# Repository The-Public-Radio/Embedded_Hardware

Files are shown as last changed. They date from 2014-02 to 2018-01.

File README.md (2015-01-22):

# PR_Public_Radio
Created 2013.12.17
by Spencer Wright |
Updated by Spencer Wright 2015.01.21

## LICENSE
In the interest of collaboration and good will, the files herein are offered for public use. Just don't be a jerk about it, etc., and do let us know if we've screwed something really big up:).
The Public Radio is licensed under a Creative Commons Attribution 4.0 License. For more info, visit https://creativecommons.org/licenses/by/4.0/

## PROJECT DESCRIPTION
The Public Radio is a single channel, single speaker FM receiver. 
As a piece of hardware, it was intended to be as simple as possible. One midrange speaker mounted inside a simple enclosure, with a single switched knob which controls power and adjusts volume.

## SYNOPSIS
The Public Radio is a project which spans industrial design, embedded systems design, and firmware. The files located within this project comprise a subset of the data reqired to fully complete ThePublic Radio, though efforts are being made to completely describe the project from top to bottom.

## CREDITS
The work herein is primarily a collaboration between Spencer Wright (http://pencerw.com) and Zach Dunham (http://zachdunham.com) though much of it was adapted heavily from friendly sources. In particular, early versions of the firmware was adapted directly from Nathan Seidle et al (Sparkfun). Special thanks also goes to Todd Bailey (http://blog.narrat1ve.com/) and Andy Warner (https://github.com/andyw-lala?tab=activity)

## Board and Layout

PR90XX is a circular PCB with an OD of 70mm and a 23mm circular cutout at its center. The cutout is designed such that the radio's speaker drops partly through the PCB; its backside passes through the cutout. The antenna and trim pot are additionally mounted directly to the board and pass through the top of the lid. Two sets of two AA battery clips are mounted on the bottom side of the board to house the two AA batteries.

Early on in the project, we planned on building a custom aluminum enclosure, but decided to protoype using an off-the-shelf container - a Ball brand mason jar. The enclosure requires one custom manufactured part: a replacement lid, to which the speaker, potentiometer, and electronics mount.

## CONTAINED HEREIN
* Embedded systems design files: Namely .brd, .sch, possibly gerbers. These will remain up-to-date, so long as we can stay on our game:)
* Firmware: Arduino sketches, library files (header & source). 
* Miscellaneous tools: This currently comprises of just a shell script used to create CSVs from EAGLE exports, which generally suck. The script is okay, though.

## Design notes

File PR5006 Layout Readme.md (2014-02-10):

#PUBLIC RADIO PR5006 Layout, Circuit Topology  
This document by Zach Dunham, 2014.02.08
Additional input by Spencer Wright

———————

##Overview 

The Public Radio v1.3 contains a significant revision in its PCB, PR5006. PR5006 consists of a mechanically tuned, FM receiver with included amplifier, speaker, AA batteries, tuning trimpot, and volume/power pot. The radio is delivered pre-tuned to the listeners chosen FM station. The radio includes a class-D amplifier, small (roughly 1”) speaker and switched potentiometer for power and and volume control. The radio runs at 3V off of two AA batteries that are fixed to the bottom of the PCB. Reception is permitted through the use of either a telescoping antenna or a fixed, solid stainless steel rod. The assembly is housed in a mason jar and attached to a custom lid.  

##Board and Layout 

PR5006 is a circular PCB with an OD of 70mm and a 23mm circular cutout at its center. The cutout is designed such that the radio's speaker drops partly through the PCB; its backside passes through the cutout allowing the solder lugs to be soldered directly to the board. The antenna and trim pot are additionally mounted directly to the board and pass through the top of the lid. Two sets of two AA battery clips are mounted on the bottom side of the board to house the two AA batteries.  

##Si4831 FM Receiver 

PR5006 utilizes the Si4831 chip in a 24 pin, SSOP package. Si4831 is a mechanically tuned digital CMOS AM/FM receiver. PR5006 only utilizes the FM functionality of the radio. Connections are as follows:

* Pins 1 & 2 - indicate stereo signal and station reception, respectively. Pin 1 is left floating since we are only functioning in mono mode. Pin 2 is tied high via R4 to set the radio in “volume mode” as opposed to “bass/treble mode” and tied high through R5 in series with an LED to indicate reception.  
* Pins 2 & 3 - form the tuning circuit of the radio along with C1, C2, trimpot R10, R1 and R3. Varying the resistance between these to pins varies the center frequency in the FM range. The radio calls for 413K at 1% between the band select pin and pin 1 of the trim pot. To keep within this tolerance we broke the 413K resistor into two resistors at 412K and 1K values.  
* Pin 5 - is the band select. According to the data sheet, pin 5 wants to see 77K resistance to ground to set the band select at 87-108MHz
* Pin 6,7 - NC 
* Pin 8 - is the FMI pin which consists of an ESD protection diode and inductor L1 to ground inline with a capacitor, C3 to pin 8 forming a high pass filter. Additionally, because our design places the antenna roughly 30 mm from pin 8, and to limit noise on the FMI line, we’ve placed restricts on both the top and bottom layer ground planes around the antenna trace.  
* Pin 9, 10, 11, 12 - tied to ground. Pin 9 is the RFGND, Pins 10, 11, 12 are part of the AM circuit tied to ground. Note, our testing with showed no loss of FM reception tying the AM to ground or leaving it floating.  
* Pin 13, 14 - also ground pins 
* Pin 15 - is the reset pin, tied high through R6 inline with C4 to ground 
* Pin 16, 17 - volume or bass/treble control. By tying pin 2 high we’re utilizing volume mode, and by tying pins 16 & 17 to ground we’re setting the output to maximum volume.  
* Pin 18 & 19 - are pins for the external 32.768 KHz oscillator with necessary loading caps (C6 and C8) tied to ground. 
* Pins 20, 21, 22 - are the power and bypass pins. Pins 20 and 21 - VDD1 and VDD2 - are connected to VCC through C5, C7.  The other leg of C5 and C7 are connected to pin 22 which is the IC’s internal bypass pin. Additionally, to mitigate noise C5 and C7 are inline with a ferrite bead connected to VCC.  
* Pins 23 and 24 - left out and right out signal to the audio amplifier

##TPA2005d1 1.4 W Mono Audio Amp
PR5006 uses this class-d audio amp to power its 1” full range driver.  

* Pin 1 - shutdown pin which is tied high through R8 inline with C10 to ground for a roughly 1/4 second delayed power up.
* Pin 2 - NC 
* Pin 3 - positive differential input from the output of the radio connected via coupling capacitor C9 and gain setting resistor R7, for a gain of roughly 6.  
* Pin 4 - negative differential input, same values as pin 3
* Pin 5 - positive output, connected to the speaker 
* Pin 6 - VDD connected to VCC through decoupling capacitors C12 and C13 along with a ferrite bead, L2
* Pin 7 - GND
* Pin 8 - negative output, connected to the speaker 

Notes!  
PR5006 has no reverse polarity protection.  The bottom solder mask design aims to provide the correct battery orientation. The following version will most likely incorporate a synchronous rectifier.

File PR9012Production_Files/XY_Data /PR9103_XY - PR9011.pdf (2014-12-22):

ITEM | PR9011 X/Y | NOTES | Do not place listed as yellow
DATE | 12.15.2014
PREPARED BY | Zach Dunham
NOTES | Development Board
CONTACT | info@thepublicrad.io
RefID | Description | Package | XPos mm | YPos mm | Orientation
AMP | TPA2005D1DGN | POWER-SOP8 | 123.7 | 13.632 | R90
C1 | 220uF | PANASONIC_C | 92.652 | 20.39 | R270
C2 | 1.0uF | 0805 | 35.314 | 40.94 | R90
C3 | 1.0uF | 0805 | 35.316 | 37.86 | R270
C4 | 22pf | 0805 | 19.75 | 40.588 | R180
C5 | 22pf | 0805 | 19.75 | 34.312 | R180
C6 | ds | 0805 | 9.132 | 7.968 | R270
C7 | 1.0uF | 0805 | 21.136 | 43.788 | R180
C8 | .1uF | 0805 | 21.136 | 42.21 | R180
C9 | 1.0uF | 0805 | 21.462 | 24 | R180
C10 | 22nF | 0805 | 20.986 | 31.768 | R180
C11 | 4.7uF | 0805 | 20.986 | 29.544 | R180
C12 | .1uf | 0805 | 112.202 | 65.024 | R180
C13 | .033uf | C0603 | 131.94 | 20.39 | R270
C14 | 10uf | 0805 | 112.202 | 67.31 | R180
C15 | 10uf | C0603 | 131.272 | 9.73 | R270
C16 | .033uf | C0603 | 129.092 | 20.34 | R270
C17 | 1uf | 0805 | 119.96 | 7.832 | R0
C18 | 10uf | 0805 | 122.666 | 17.082 | R180
C19 | .1uf | 0805 | 122.666 | 19.292 | R180
C20 | 100pf | 0805 | 120.01 | 9.992 | R0
D1 | | SOT23-3 | 38.39 | 39.864 | R180
FB1 | | 0805 | 30.578 | 36.75 | R180
FB2 | | 0805 | 115.664 | 15.2 | R180
FB3 | | 0805 | 115.7 | 12.6 | R0
FET1 | AO3435 | AO3435 | 99.786 | 21.144 | R0
FMA_OUT | M01PTH | 1X01 | 20.456 | 20.796 | R270
FMHEADER | M10LOCK | 1X10_LOCK | 4.928 | 54.61 | R270
FMIC | SI4703 | SPARKFUN_SI470X | 26.468 | 37.49 | R180
GND. | M01PTH | 1X01 | 138.61 | 78.242 | R0
GND2. | M01PTH | 1X01 | 33.26 | 65.158 | R0
GND3. | M01PTH | 1X01 | 31.41 | 5.432 | R0
GND4. | M01PTH | 1X01 | 137.66 | 7.948 | R0
ISP | AVR_SPI_PRG_6NS | 2X3-NS | 137.348 | 66.802 | R270
J1 | M3_SCREW_POST | M3_SCREW_POST | 47.686 | 38.1 | R0
JP5 | BK-92_MPD_AA_BA | BK-92_MPD_AA_BATT_CLIP | 114.742 | 89.662 | R0
JP6 | BK-92_MPD_AA_BA | BK-92_MPD_AA_BATT_CLIP | 54.29 | 89.662 | R0
JST_CONN | | JST-PH-2-SMT-RA | 104.05 | 6.45 | R90
L1 | | 0805 | 33.214 | 38.726 | R90
L2 | 2.5k@100MHz | 0603 | 25.766 | 29.764 | R180
L3 | 2.5 | 0603 | 115.622 | 17.72 | R0
LED1 | | SML0603 | 117.438 | 52.012 | R90
LID | M01PTH | 1X01 | 9.17 | 14.054 | R0
MCU | Tiny85-20-SMT | SO08-EIAJ | 116.774 | 66.548 | R0
PWR | M02PTH3 | 1X02_LONGPADS | 86.45 | 79.486 | R180
R1 | RV170SF_TAIWANA | RV170SF_TAIWANA_POT_SW | 98.74 | 38.1 | R270
R2 | 330 | 0805 | 29.736 | 47.2 | R90
R3 | 330 | 0805 | 28.234 | 47.2 | R90
R4 | 330 | 0805 | 22.136 | 47.15 | R90
R5 | 330 | 0805 | 20.488 | 47.15 | R90
R6 | 10K | 0805 | 31.286 | 47.218 | R270
R7 | 4.7K | 0805 | 23.638 | 47.168 | R90
R8 | 4.7K | 0805 | 25.236 | 47.168 | R90
R9 | 4.7K | 0805 | 26.734 | 47.168 | R90
R10 | | 0805 | 9.146 | 11.068 | R90
R11 | 40.2K | R0603 | 131.94 | 16.526 | R270
R12 | 10K | R0603 | 128.428 | 9.66 | R270
R13 | 40.2K | R0603 | 129.042 | 16.476 | R270
R14 | 1K | R0603 | 117.436 | 56.812 | R90
R15 | 10K | R0603 | 115.1 | 56.85 | R90
SCLK. | M01PTH | 1X01 | 26.806 | 55.09 | R0
SDIO. | M01PTH | 1X01 | 37.456 | 51.838 | R0
SW1 | SPST_TACT-KMR2 | KMR2 | 137.092 | 50.266 | R90
U$1 | FIDUCIAL | FIDUCIAL_1MM | 128.6 | 42.2 | R0
U$2 | FIDUCIAL | FIDUCIAL_1MM | 6.1 | 90.7 | R0
U$4 | FIDUCIAL | FIDUCIAL_1MM | 20.6 | 10.6 | R0
VARI | | 146/150 | 34.7 | 31.85 | R180
Y1 | 32.768kHz | CRYSTAL-32KHZ-SMD | 20 | 37.49 | R90

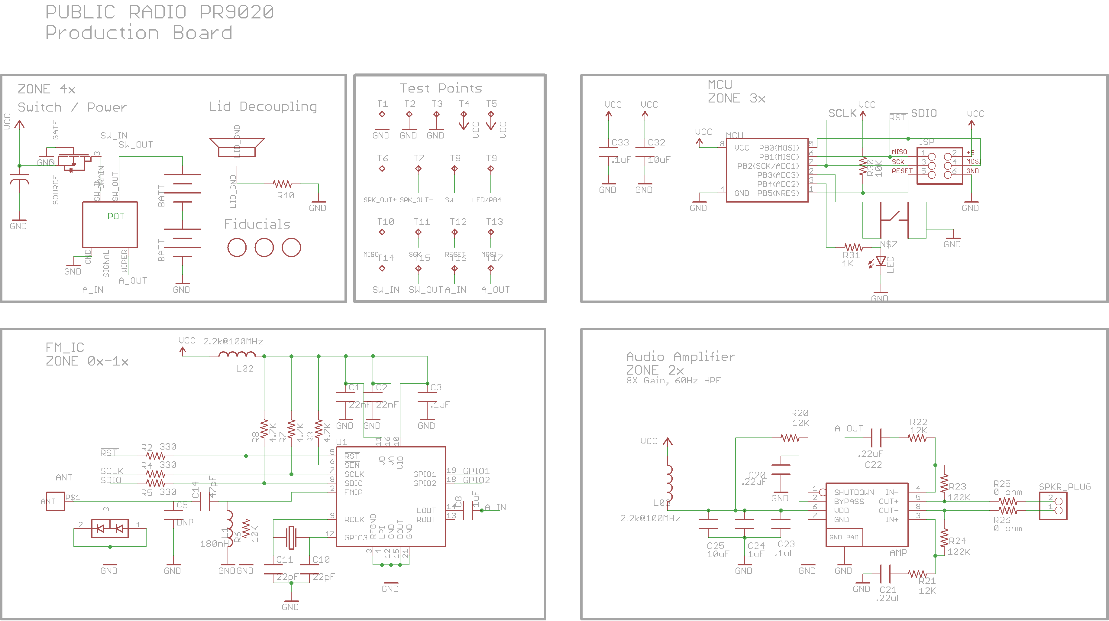
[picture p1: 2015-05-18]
EAGLE_CAD/PR9020/PR9020_SCH.png

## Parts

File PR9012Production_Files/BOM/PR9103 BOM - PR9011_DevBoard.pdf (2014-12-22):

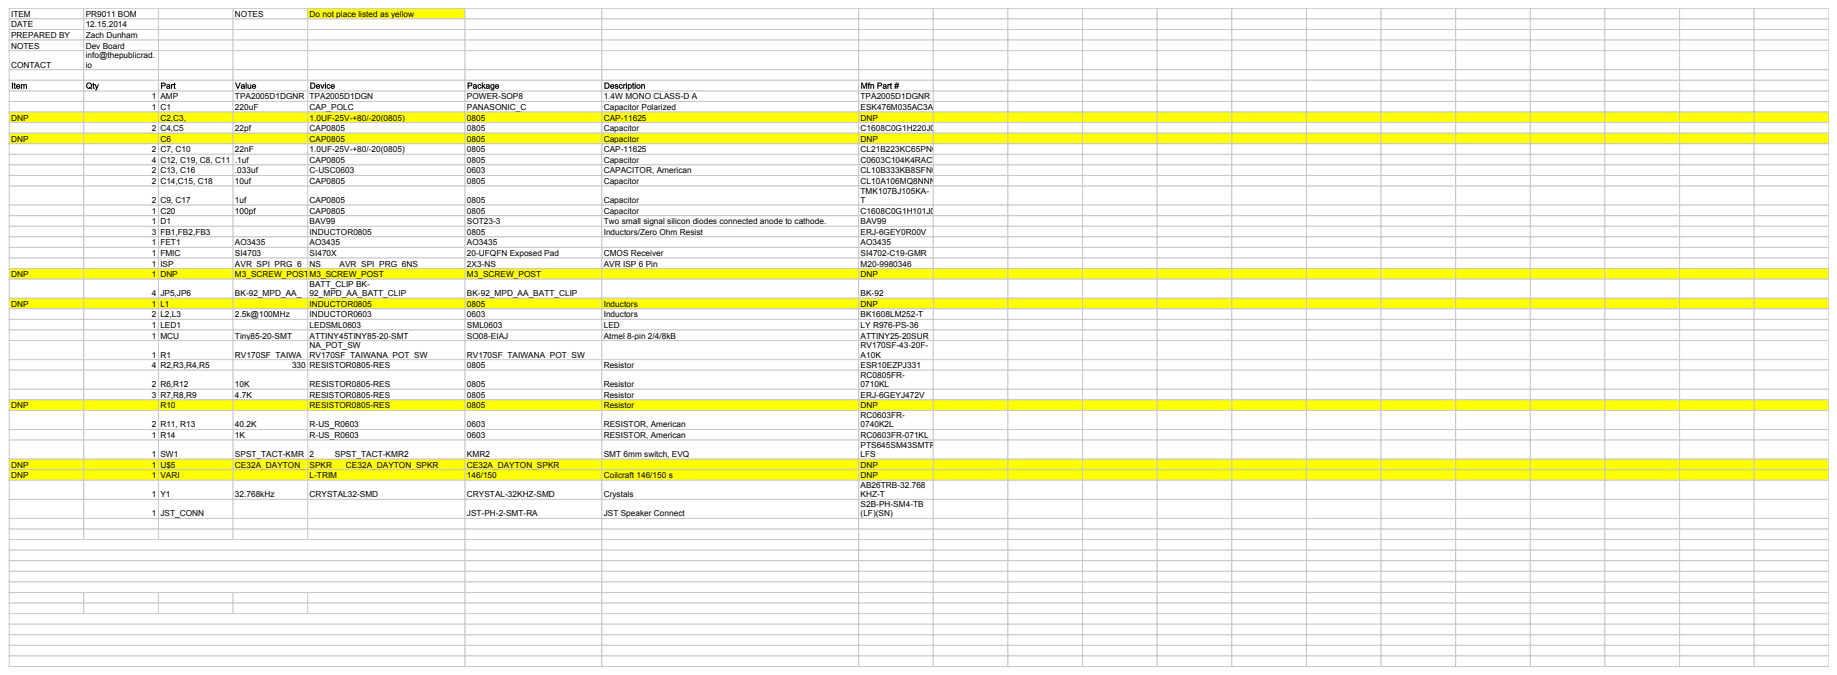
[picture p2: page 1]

ITEM | PR9011 BOM | NOTES | Do not place listed as yellow
DATE | 12.15.2014 PREPARED BY Zach Dunham

NOTES | Dev Board
CONTACT | info@thepublicrad. io

Item | Qty | Part | Value | Device | Package | Description | Mfn Part #

1 | C1 C2,C3, | 220uF | CAP_POLC 1.0UF-25V-+80/-20(0805) | PANASONIC_C 0805 | Capacitor Polarized CAP-11625 | ESK476M035AC3AA DNP DNP

1 | AMP | TPA2005D1DGNR | TPA2005D1DGN | POWER-SOP8 | 1.4W MONO CLASS-D A | TPA2005D1DGNR

2 | C4,C5 C6 | 22pf | CAP0805 | 0805 | Capacitor | C1608C0G1H220J080AA DNP DNP

2 | C7, C10 | 22nF | 1.0UF-25V-+80/-20(0805) | 0805 | CAP-11625 | CL21B223KC65PNC
4 | C12, C19, C8, C11 | .1uf | CAP0805 | 0805 | Capacitor | C0603C104K4RACTU
2 | C13, C16 | .033uf | C-USC0603 | 0603 | CAPACITOR, American | CL10B333KB8SFNC
2 | C14,C15, C18 | 10uf | CAP0805 | 0805 | Capacitor | CL10A106MQ8NNNC
2 | C9, C17 | 1uf | CAP0805 | 0805 | Capacitor | TMK107BJ105KA- T

1 | C20 | 100pf | CAP0805 | 0805 | Capacitor | C1608C0G1H101J080AA
1 | D1 | | BAV99 | SOT23-3 | Two small signal silicon diodes connected anode to cathode. | BAV99
3 | FB1,FB2,FB3 | | INDUCTOR0805 | 0805 | Inductors/Zero Ohm Resist | ERJ-6GEY0R00V
1 | FET1 | AO3435 | AO3435 | AO3435 | | AO3435
1 | FMIC | SI4703 | SI470X | 20-UFQFN Exposed Pad | CMOS Receiver | SI4702-C19-GMR

1 1 | ISP DNP | AVR_SPI_PRG_6 M3_SCREW_POSTM3_SCREW_POST | NS AVR_SPI_PRG_6NS | 2X3-NS M3_SCREW_POST | AVR ISP 6 Pin | M20-9980346 DNP DNP

1 4 | L1 JP5,JP6 | BK-92_MPD_AA_ | BATT_CLIP BK- 92_MPD_AA_BATT_CLIP INDUCTOR0805 | BK-92_MPD_AA_BATT_CLIP 0805 | Inductors | BK-92 DNP DNP

2 | L2,L3 | 2.5k@100MHz | INDUCTOR0603 | 0603 | Inductors | BK1608LM252-T
1 | LED1 | | LEDSML0603 | SML0603 | LED | LY R976-PS-36
1 | MCU | Tiny85-20-SMT | ATTINY45TINY85-20-SMT | SO08-EIAJ | Atmel 8-pin 2/4/8kB | ATTINY25-20SUR
1 | R1 | RV170SF_TAIWA | NA_POT_SW RV170SF_TAIWANA_POT_SW | RV170SF_TAIWANA_POT_SW | | RV170SF-43-20F- A10K

4 | R2,R3,R4,R5 | 330 | RESISTOR0805-RES | 0805 | Resistor | ESR10EZPJ331
2 | R6,R12 | 10K | RESISTOR0805-RES | 0805 | Resistor | RC0805FR- 0710KL

3 | R7,R8,R9 R10 | 4.7K | RESISTOR0805-RES | 0805 | Resistor | ERJ-6GEYJ472V DNP DNP

2 | R11, R13 | 40.2K | R-US_R0603 | 0603 | RESISTOR, American | RC0603FR- 0740K2L

1 | R14 | 1K | R-US_R0603 | 0603 | RESISTOR, American | RC0603FR-071KL
1 | SW1 | SPST_TACT-KMR | 2 SPST_TACT-KMR2 | KMR2 | SMT 6mm switch, EVQ | PTS645SM43SMTR92

1 1 | U$5 VARI | CE32A_DAYTON_ | SPKR L-TRIM CE32A_DAYTON_SPKR | CE32A_DAYTON_SPKR 146/150 | Coilcraft 146/150 s | LFS DNP DNP DNP DNP

1 | Y1 | 32.768kHz | CRYSTAL32-SMD | CRYSTAL-32KHZ-SMD | Crystals | AB26TRB-32.768 KHZ-T

1 | JST_CONN | | | JST-PH-2-SMT-RA | JST Speaker Connect | S2B-PH-SM4-TB (LF)(SN)

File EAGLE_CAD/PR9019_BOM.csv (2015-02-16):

Qty | Value | Device | Package | Parts | Description | CURRENT | DCR | MFG_PN | POWER | TOL | VOLTAGE
1 |  | ABS25XTAL | 4-SOJ | X1 | 4PIN 32.768 Xtal |  |  | ABS25-32.768KHZ-T
1 |  | AO3435 | SOT23_CPL | FET1 | MOSFET P-CH 20V 2.9A SOT23 |  |  | AO3435
1 |  | ATTINY45TINY45-20-SMT | 8-SOIC | MCU | Atmel 8-pin 2/4/8kB flash uC |  |  | ATTINY45-20SUR
1 |  | AVR_SPI_PRG_6NS | 2X3-NS | ISP | DIL VERTICAL PC TAIL PIN HEADER |  |  | M20-9980346
1 |  | BAV99 | SOT23_CPL | D1 | DIODE ARRAY GP 100V 215MA SOT23 |  |  | BAV99 | 215
2 |  | BK-92_MPD_AA_BATT_CLIP | BK92_AA_BATT | JP5, JP6 | Thru hole AA battery clip pair. |  |  | 2 of BK92 - supplied by CL Labs
1 |  | C&K_PTS645 | C&K_PTS645_SMT | SW1 | SWITCH TACTILE SPST-NO 0.05A 12V |  |  | PTS645SM43SMTR92 LFS
3 |  | FIDUCIAL | FIDUCIAL_1MM | MARK1, MARK2, MARK3 | 1mm fiducial. |  |  | DNP
1 |  | JST_2PIN-SMT-RA | JST-B2B-PH-SM4-TB | SPKR_PLUG | JST 2-pin connector |  |  | B2B-PH-SM4-TB(LF)(SN)
2 |  | L_SMT_0805_ADAFRUIT | 0805_ADAFRUIT | FB2, FB3 | SMT inductor | 2A | 45m | HI0805R800R-10
1 |  | RV170SF_TAIWANA_POT_SW | RV170SF_SW_POT | R1 | Thru hole switched potentiometer. |  |  | RV170SF-43-20F-A10K - supplied by CL Labs
1 |  | SI4702-C19-GMR | SI470X_20_QFN | U1 | IC FM RADIO TUNER 20-QFN |  |  | Si4702 C19 GM - supplied by CL Labs
1 |  | TPA6203A1 | 8-MSOP | AMP | IC AMP AUDIO PWR 1.25W AB 8MSOP |  |  | TPA6203A1DGNR
17 |  | TPTP20R | TP20R | T1, T2, T3, T4, T5, T6, T7, T8, T9, T10, T11, T12, T13, T14, T15, T16, T17 | Test pad |  |  | DNP
3 | .1uF | C_SMT_0603_CPL | 0603_CPL | C3, C23, C33 | SMT capacitor |  |  | CL10B104KB8SFNC |  | 10% | 16V
3 | .22uF | C_SMT_0603_CPL | 0603_CPL | C20, C21, C22 | SMT capacitor |  |  | C1608X7R1C224K080AC |  | 10% | 16V
2 | 100K | R_SMT_R0603_CPL | 0603_CPL | R23, R24 | SMT resistor |  |  | ERJ-3EKF1003V | 1/10W | 1%
3 | 10K | R_SMT_R0603_CPL | 0603_CPL | R6, R20, R30 | SMT resistor |  |  | ERJ-3GEYJ103V | 1/10W | 5%
2 | 10uF | C_SMT_0603_CPL | 0603_CPL | C25, C32 | SMT capacitor |  |  | CL10A106MQ8NNNC |  | 20% | 6.3V
2 | 12K | R_SMT_R0603_CPL | 0603_CPL | R21, R22 | SMT resistor |  |  | RC0603FR-0712KL | 1/10W | 1%
1 | 180nH | L_SMT_0805_ADAFRUIT | 0805_ADAFRUIT | L1 | SMT inductor | 400mA | 640m | AISC-0805-R18J-T |  | 5%
1 | 1K | R_SMT_R0603_CPL | 0603_CPL | R31 | SMT resistor |  |  | ERJ-3EKF1001V | 1/10W | 1%
2 | 1uF | C_SMT_0603_CPL | 0603_CPL | C8, C24 | SMT capacitor |  |  | CL10B105KP8NNNC |  | 10% | 10V
2 | 2.2k@100MHz | L_SMT_0603_CPL | 0603_CPL | L02, L03 | SMT inductor | 150mA | 2.3 | HZ0603A222R-10
1 | 220uF | NICHICON_SERIESUD | NICHICON_UD_63 | C40 | Nichicon UD Series 220uf Cap |  |  | UUD1C221MCL1GS |  | 20% | 16V
2 | 22nF | C_SMT_0603_CPL | 0603_CPL | C1, C2 | SMT capacitor |  |  | CL10B223KB8NNNC |  | 10% | 16V
2 | 22pF | C_SMT_0603_CPL | 0603_CPL | C10, C11 | SMT capacitor |  |  | C1608C0G1H220J080AA |  | 5% | 50V
3 | 330 | R_SMT_R0603_CPL | 0603_CPL | R2, R4, R5 | SMT resistor |  |  | MCR03ERTJ331 | 1/10W | 5%
3 | 4.7K | R_SMT_R0603_CPL | 0603_CPL | R3, R7, R8 | SMT resistor |  |  | ERJ-3EKF4701V | 1/10W | 1%
1 | 47pF | C_SMT_0603_CPL | 0603_CPL | C14 | SMT capacitor |  |  | CL10C470JB8NCNC |  | 5% | 50V
1 | DNP | C_SMT_0603_CPL | 0603_CPL | C5 | SMT capacitor |  |  | DNP |  | 2% | 50V
1 | DNP | M3_SCREW_POST | M3_BOLT_HOLE | ANT_MOUNT | Antenna mounting hole for M3 screw. |  |  | DNP
1 | DNP | PR2023_SPKR | PR2023_SPKR_PLACE | SPKR_PLACE | Speaker placement for PR2023. |  |  | DNP
1 | DNP | R_SMT_R0603_CPL | 0603_CPL | R40 | SMT resistor |  |  | ERJ-3GEY0R00V
1 | LED | LED | 0603_CPL | LED | SMT LED |  |  | LY R976-PS-36

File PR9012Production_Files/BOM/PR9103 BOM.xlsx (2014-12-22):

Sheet: PR9011_DevBoard
ITEM | PR9011 BOM |  | NOTES | Do not place listed as yellow
DATE | 12.15.2014
PREPARED BY | Zach Dunham
NOTES | Dev Board
CONTACT | info@thepublicrad.io
Item | Qty | Part | Value | Device | Package | Description | Mfn Part #
 | 1 | AMP | TPA2005D1DGNR | TPA2005D1DGN | POWER-SOP8 | 1.4W MONO CLASS-D A | TPA2005D1DGNR
 | 1 | C1 | 220uF | CAP_POLC | PANASONIC_C | Capacitor Polarized | ESK476M035AC3AA
DNP |  | C2,C3, |  | 1.0UF-25V-+80/-20(0805) | 0805 | CAP-11625 | DNP
 | 2 | C4,C5 | 22pf | CAP0805 | 0805 | Capacitor | C1608C0G1H220J080AA
DNP |  | C6 |  | CAP0805 | 0805 | Capacitor | DNP
 | 2 | C7, C10 | 22nF | 1.0UF-25V-+80/-20(0805) | 0805 | CAP-11625 | CL21B223KC65PNC
 | 4 | C12, C19, C8, C11 | .1uf | CAP0805 | 0805 | Capacitor | C0603C104K4RACTU
 | 2 | C13, C16 | .033uf | C-USC0603 | 0603 | CAPACITOR, American | CL10B333KB8SFNC
 | 2 | C14,C15, C18 | 10uf | CAP0805 | 0805 | Capacitor | CL10A106MQ8NNNC
 | 2 | C9, C17 | 1uf | CAP0805 | 0805 | Capacitor | TMK107BJ105KA-T
 | 1 | C20 | 100pf | CAP0805 | 0805 | Capacitor | C1608C0G1H101J080AA
 | 1 | D1 |  | BAV99 | SOT23-3 | Two small signal silicon diodes connected anode to cathode. | BAV99
 | 3 | FB1,FB2,FB3 |  | INDUCTOR0805 | 0805 | Inductors/Zero Ohm Resist | ERJ-6GEY0R00V
 | 1 | FET1 | AO3435 | AO3435 | AO3435 |  | AO3435
 | 1 | FMIC | SI4703 | SI470X | 20-UFQFN Exposed Pad | CMOS Receiver | SI4702-C19-GMR
 | 1 | ISP | AVR_SPI_PRG_6 | NS AVR_SPI_PRG_6NS | 2X3-NS | AVR ISP 6 Pin | M20-9980346
DNP | 1 | DNP | M3_SCREW_POST | M3_SCREW_POST | M3_SCREW_POST |  | DNP
 | 4 | JP5,JP6 | BK-92_MPD_AA_ | BATT_CLIP BK-92_MPD_AA_BATT_CLIP | BK-92_MPD_AA_BATT_CLIP |  | BK-92
DNP | 1 | L1 |  | INDUCTOR0805 | 0805 | Inductors | DNP
 | 2 | L2,L3 | 2.5k@100MHz | INDUCTOR0603 | 0603 | Inductors | BK1608LM252-T
 | 1 | LED1 |  | LEDSML0603 | SML0603 | LED | LY R976-PS-36
 | 1 | MCU | Tiny85-20-SMT | ATTINY45TINY85-20-SMT | SO08-EIAJ | Atmel 8-pin 2/4/8kB | ATTINY25-20SUR
 | 1 | R1 | RV170SF_TAIWA | NA_POT_SW RV170SF_TAIWANA_POT_SW | RV170SF_TAIWANA_POT_SW |  | RV170SF-43-20F-A10K
 | 4 | R2,R3,R4,R5 | 330 | RESISTOR0805-RES | 0805 | Resistor | ESR10EZPJ331
 | 2 | R6,R12 | 10K | RESISTOR0805-RES | 0805 | Resistor | RC0805FR-0710KL
 | 3 | R7,R8,R9 | 4.7K | RESISTOR0805-RES | 0805 | Resistor | ERJ-6GEYJ472V
DNP |  | R10 |  | RESISTOR0805-RES | 0805 | Resistor | DNP
 | 2 | R11, R13 | 40.2K | R-US_R0603 | 0603 | RESISTOR, American | RC0603FR-0740K2L
 | 1 | R14 | 1K | R-US_R0603 | 0603 | RESISTOR, American | RC0603FR-071KL
 | 1 | SW1 | SPST_TACT-KMR | 2 SPST_TACT-KMR2 | KMR2 | SMT 6mm switch, EVQ | PTS645SM43SMTR92 LFS
DNP | 1 | U$5 | CE32A_DAYTON_ | SPKR CE32A_DAYTON_SPKR | CE32A_DAYTON_SPKR |  | DNP
DNP | 1 | VARI |  | L-TRIM | 146/150 | Coilcraft 146/150 s | DNP
 | 1 | Y1 | 32.768kHz | CRYSTAL32-SMD | CRYSTAL-32KHZ-SMD | Crystals | AB26TRB-32.768KHZ-T
 | 1 | JST_CONN |  |  | JST-PH-2-SMT-RA | JST Speaker Connect | S2B-PH-SM4-TB(LF)(SN)

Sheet: PR9011 Notes
Suggestions for 0805 L1 - source both 150 and 180nH variants (links are 150nH, I think) (20 each value)
http://www.digikey.com/product-detail/en/CW201212-R15J/CW201212-R15JCT-ND/3741341
http://www.digikey.com/product-detail/en/AISC-0805-R15J-T/535-10503-1-ND/2335460
http://www.digikey.com/product-detail/en/AISC-0805-R15G-T/AISC-0805-R15G-TCT-ND/3060495
http://www.digikey.com/product-detail/en/4-1624113-9/A103761CT-ND/2730092
Suggestions for C2 & C3 - source 10, 12, 15, 18, 22, 27, 33, 39, 42 & 47 pF variants (25 each value)
http://www.digikey.com/product-detail/en/C0805C220J5GACTU/399-1113-1-ND/411388
http://www.digikey.com/product-detail/en/500R15N220JV4T/709-1172-1-ND/1859504
http://www.digikey.com/product-detail/en/CL21C220JBANNNC/1276-1047-1-ND/3889133
http://www.digikey.com/product-detail/en/08055A220JAT2A/478-1308-1-ND/564340

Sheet: Old_PR9011
Item | Qty | Reference | Mfr. Part No. | Description | Value | Custom | Notes
1 | 1 | FMIC | SI4702-C19-GMR | FM IC | -
2 | 1 | MCU | ATTINY25-20SUR | MCU | -
3 | 1 | AMP | TPA2005D1 | AMP | -
4 | 1 | FET1 | SI2333DDS-T1-GE3 | Reverse Polarity FET
5 | 1 | D1 | BAV99 | ESD DIODE
6 | 1 | SW1 | PTS645SM43SMTR92 LFS | TACTILE SWITCH
7 | 1 | LED1 | LY R976-PS-36 | LED
8 | 4 | JP5/JP6 | BK-92 | BATT CLIP | -
9 | 2 | L2/L3 | BK1608LM252-T | FERRITE BEAD |  |  | thru hole
10 | 1 | Y1 | AB26TRB-32.768KHZ-T | XTAL | 32.768
11 | 1 | C1 | UWT1C221MCL1GS | VCC Decouple Cap | 220uf
12 | 1 | R1 | RV170SF-43-20F-A10K | Vol / PWR Pot, Taiwan Alpha | A10K | non-stock | thru hole
13 | 4 | R2/R3/R4/R5 | ESR10EZPJ331 | Resistor | 330
14 | 4 | R7/R8/R9 | ERJ-6GEYJ472V | i2c Pullup | 4.7K
15 | 2 | C4/C5 | C1608C0G1H220J080AA | XTAL Cap | 22pF
16 | 1 | C9 | EMK107ABJ475KA-T | FM Audio Coupling | 4.7uF
17 | 3 | C14/C15/C18 | CL10A106MQ8NNNC | Decoupling | 10uF
18 | 2 | C12/C19 | C0603C104K4RACTU | Decoupling | .1uF
19 | 2 | C13/C16 | CL10B333KB8SFNC | Amp Filter | .033uF
20 | 2 | R11/R13 | RC0603FR-0740K2L | Amp Gain | 40.2K
21 | 2 | R6/R12 | RC0603FR-0710KL |  | 10K
22 | 1 | R14 | RC0603FR-071KL | Current Limit Led | 1K
23 | 1 | C17 | TMK107BJ105KA-T | Amp Decouple | 1uF
24 | 1 | C20 | C1608C0G1H101J080AA | Amp Decouple | 100pF
DNP | 1 | L1 | N/A | TUNING INDUCTOR
DNP | 1 | C2 |  | Tuning Cap
DNP | 1 | C3 |  | Tuning Cap
DNP | 1 | C7 |  | FMIC Decoupling
DNP | 1 | C8 |  | FMIC Decoupling
DNP | 1 | C10 |  | FMIC Decoupling
DNP | 1 | C11 |  | FMIC Decoupling

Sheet: obsolete 1
Location | Description | Value | Mfr. Part No. | Qty per radio | Custom | Notes
A01 | C9, C11 | .033uF | CL10B333KB8SFNC | 2
A05 | R7, R9 | 40.2K | RC0603FR-0740K2L | 2
A10 | R5 | 220ohm | RC0603JR-07220RL | 1
A11 | R2 | 77K | RC0603FR-0776K8L | 1
A12 | C3 | 1nF | C0603C102K5RACTU | 1
A13 | C1 | 47uF | ESK476M035AC3AA | 1
A14 | C14 | 220uF | UVR0J221MDD | 1
A23-24 | Trimpot | 100K (12turn) | 64XR100KLF | 1
C01 | C17 | 470pF | CL21C471JCCNFNC | 1
C02 | C18, C20 | 100pF | C1608C0G1H101J080AA | 2
C10 | R13 | 0 ohm | ERJ-3GEY0R00V | 1
C11 | C15, C16 | 2.2uF | JMK107BJ225KA-T | 2
C12 | FET |  | SI2333DDS | 1
E00 | L1(rec) | 75nH | LQW18AN75NG00D | 1
E01 | C6, C8 | 22pF | C1608C0G1H220J080AA | 2
E02 | R6 | 100K | RC0603JR-07100KL | 1
E03 | L2, L3 Ferrite |  | BK1608LM252-T | 2
E04 | ESD Diode |  | CM1213A-01SO | 1
E05 | C10, C12 | 10uF | CL10A106MQ8NNNC | 2
E10 | LED |  | LY R976-PS-36 | 1
E11 | C7 | 4.7uF | EMK107ABJ475KA-T | 1
E13 | R4, R8 | 10K | RC0603FR-0710KL | 2
E15 | R3 | 1K | RC0603FR-071KL | 1
E20 | R10 | 100ohm | RC0603FR-07100RL | 1
E21 | XTAL | 32.768KHz | AB26TRB-32.768KHZ-T | 1
E22 | C2, C4, C5, C19 | .1uF | C0603C104K4RACTU | 4
E23 | Amp |  | TPA2005D1 | 1
E24 | R1 | 412K | RC0603FR-07412KL | 1
E25 | C13 | 1uF | TMK107BJ105KA-T | 1
 | Vol / PWR Pot, Taiwan Alpha | A10K | RV170SF-43-20F-A10K | 1 | Yes
 | FM IC |  | SI4831-B30-GUR | 1
 | Speaker |  | CE32A-4 | 1 |  | Dayton Audio
 | Battery Clip |  | BK-92 | 4
 | Antenna Screw |  | McMaster# 92000A118 | 1 |  | 18-8 Stainless Steel Metric Pan Head Phillips Machine Screw, M3 Size, 8mm Length, .5mm Pitch
 | Antenna Nut |  | McMaster# 91828A211 | 1 |  | Metric 18-8 Stainless Steel Hex Nut, M3 Size, .5mm Pitch, 5.5mm Width, 2.4mm Height
 | Antenna |  |  | 1 | Yes | Sinowares Tech

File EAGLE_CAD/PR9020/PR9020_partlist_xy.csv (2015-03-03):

Part name | xpos | ypos
AMP | 36 | 8.1
ANT_MOUNT | 9.5 | 35
C1 | 29.01 | 59.6
C2 | 24.7 | 59.6
C3 | 30.24 | 58.03
C5 | 24.6 | 52.7
C8 | 34.2 | 51.7
C10 | 24.7 | 61.3
C11 | 29 | 61.3
C14 | 24.6 | 54
C20 | 41.9 | 5.9
C21 | 41.9 | 7.1
C22 | 39.2 | 11.9
C23 | 31.1 | 9.1
C24 | 31.1 | 10.3
C25 | 31.1 | 7.8
C32 | 43.6 | 51.7
C33 | 40.6 | 51.7
C40 | 45 | 14
D1 | 16.4 | 43.5
FB2 | 31.1 | 12.1
FB3 | 31.11 | 5.94
FET1 | 59.4 | 20.5
ISP | 43.8 | 64.2
JP5 | 35 | 53.5
JP6 | 35 | 16.5
L1 | 22 | 53.2
L02 | 34.7 | 61.3
L03 | 34.4 | 14
LED | 64.2 | 50
MARK1 | 16.2 | 8.5
MARK2 | 33 | 67
MARK3 | 67 | 35
MCU | 43.8 | 55.4
R1 | 60.5 | 35
R2 | 29.5 | 53.1
R3 | 30.6 | 54.4
R4 | 34.8 | 54.4
R5 | 34.8 | 56.8
R6 | 29.5 | 51.7
R7 | 34.8 | 55.6
R8 | 34.8 | 58
R20 | 36 | 4.4
R21 | 41.7 | 8.7
R22 | 39.2 | 10.7
R23 | 36 | 10.7
R24 | 36 | 5.7
R30 | 47.3 | 52
R31 | 62 | 50
R40 | 31.6 | 17.6
SPKR_PLACE | 35 | 35
SPKR_PLUG | 22.4 | 9.6
SW1 | 52.8 | 59.9
T1 | 10.6 | 44.6
T2 | 60 | 35
T3 | 60 | 30
T4 | 60 | 40
T5 | 34 | 64
T6 | 19 | 6
T7 | 28 | 5
T8 | 51 | 63
T9 | 54 | 62
T10 | 49 | 64
T11 | 37 | 67
T12 | 37 | 64
T13 | 39 | 68
T14 | 66 | 24.5
T15 | 66 | 45.5
T16 | 53 | 27
T17 | 48 | 37
U1 | 26.9 | 56.9
X1 | 27.2 | 64.58

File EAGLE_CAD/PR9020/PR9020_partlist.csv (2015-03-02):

Partlist
Exported from PR9020.brd at 3/2/15 2:28 PM
EAGLE Version 7.2.0 Copyright (c) 1988-2014 CadSoft
Assembly variant:
Part       Value          Package           Library          Position (mm)         Orientation
AMP                       8-MSOP            PR_Parts_Library (36 8.1)              R90
ANT_MOUNT  DNP            M3_BOLT_HOLE      PR_Parts_Library (9.5 35)              R0
C1         22nF           0603_CPL          PR_Parts_Library (29.01 59.6)          R180
C2         22nF           0603_CPL          PR_Parts_Library (24.7 59.6)           R0
C3         .1uF           0603_CPL          PR_Parts_Library (30.24 58.03)         R0
C5         DNP            0603_CPL          PR_Parts_Library (24.6 52.7)           R180
C8         1uF            0603_CPL          PR_Parts_Library (34.2 51.7)           R0
C10        22pF           0603_CPL          PR_Parts_Library (24.7 61.3)           R0
C11        22pF           0603_CPL          PR_Parts_Library (29 61.3)             R180
C14        47pF           0603_CPL          PR_Parts_Library (24.6 54)             R180
C20        .22uF          0603_CPL          PR_Parts_Library (41.9 5.9)            R180
C21        .22uF          0603_CPL          PR_Parts_Library (41.9 7.1)            R180
C22        .22uF          0603_CPL          PR_Parts_Library (39.2 11.9)           R180
C23        .1uF           0603_CPL          PR_Parts_Library (31.1 9.1)            R180
C24        1uF            0603_CPL          PR_Parts_Library (31.1 10.3)           R180
C25        10uF           0603_CPL          PR_Parts_Library (31.1 7.8)            R180
C32        10uF           0603_CPL          PR_Parts_Library (43.6 51.7)           R0
C33        .1uF           0603_CPL          PR_Parts_Library (40.6 51.7)           R180
C40        220uF          NICHICON_UD_63    PR_Parts_Library (45 14)               R90
D1                        SOT23_CPL         PR_Parts_Library (16.4 43.5)           R315
FB2                       0805_ADAFRUIT     PR_Parts_Library (31.1 12.1)           R180
FB3                       0805_ADAFRUIT     PR_Parts_Library (31.11 5.94)          R0
FET1                      SOT23_CPL         PR_Parts_Library (59.4 20.5)           R0
ISP                       2X3-NS            PR_Parts_Library (43.8 64.2)           MR0
JP5                       BK92_AA_BATT      PR_Parts_Library (35 53.5)             MR180
JP6                       BK92_AA_BATT      PR_Parts_Library (35 16.5)             MR0
L1         180nH          0805_ADAFRUIT     PR_Parts_Library (22 53.2)             R270
L02        2.2k@100MHz    0603_CPL          PR_Parts_Library (34.7 61.3)           R270
L03        2.2k@100MHz    0603_CPL          PR_Parts_Library (34.4 14)             R180
LED                       CHIPLED_0805      adafruit         (64.2 50)             R180
MARK1                     FIDUCIAL_1MM      PR_Parts_Library (16.2 8.5)            R0
MARK2                     FIDUCIAL_1MM      PR_Parts_Library (33 67)               R0
MARK3                     FIDUCIAL_1MM      PR_Parts_Library (67 35)               R0
MCU                       8-SOIC            PR_Parts_Library (43.8 55.4)           R90
R1                        RV170SF_SW_POT    PR_Parts_Library (60.5 35)             R270
R2         330            0603_CPL          PR_Parts_Library (29.5 53.1)           R180
R3         4.7K           0603_CPL          PR_Parts_Library (30.6 54.4)           R0
R4         330            0603_CPL          PR_Parts_Library (34.8 54.4)           R180
R5         330            0603_CPL          PR_Parts_Library (34.8 56.8)           R180
R6         10K            0603_CPL          PR_Parts_Library (29.5 51.7)           R180
R7         4.7K           0603_CPL          PR_Parts_Library (34.8 55.6)           R0
R8         4.7K           0603_CPL          PR_Parts_Library (34.8 58)             R0
R20        10K            0603_CPL          PR_Parts_Library (36 4.4)              R180
R21        12K            0603_CPL          PR_Parts_Library (41.7 8.7)            R180
R22        12K            0603_CPL          PR_Parts_Library (39.2 10.7)           R0
R23        100K           0603_CPL          PR_Parts_Library (36 10.7)             R180
R24        100K           0603_CPL          PR_Parts_Library (36 5.7)              R0
R30        10K            0603_CPL          PR_Parts_Library (47.3 52)             R0
R31        1K             0603_CPL          PR_Parts_Library (62 50)               R90
R40        DNP            0603_CPL          PR_Parts_Library (31.6 17.6)           R180
SPKR_PLACE DNP            PR2023_SPKR_PLACE PR_Parts_Library (35 35)               R0
SPKR_PLUG                 JST-B2B-PH-SM4-TB PR_Parts_Library (22.4 9.6)            R0
SW1                       C&K_PTS645_SMT    PR_Parts_Library (52.8 59.9)           R325
T1                        TP20R             PR_Parts_Library (10.6 44.6)           MR0
T2                        TP20R             PR_Parts_Library (60 35)               MR0
T3                        TP20R             PR_Parts_Library (60 30)               MR0
T4                        TP20R             PR_Parts_Library (60 40)               MR0
T5                        TP20R             PR_Parts_Library (34 64)               MR0
T6                        TP20R             PR_Parts_Library (19 6)                MR0
T7                        TP20R             PR_Parts_Library (28 5)                MR0
T8                        TP20R             PR_Parts_Library (51 63)               MR0
T9                        TP20R             PR_Parts_Library (54 62)               MR0
T10                       TP20R             PR_Parts_Library (49 64)               MR0
T11                       TP20R             PR_Parts_Library (37 67)               MR0
T12                       TP20R             PR_Parts_Library (37 64)               MR0
T13                       TP20R             PR_Parts_Library (39 68)               MR0
T14                       TP20R             PR_Parts_Library (66 24.5)             MR0
T15                       TP20R             PR_Parts_Library (66 45.5)             MR0
T16                       TP20R             PR_Parts_Library (53 27)               MR0
T17                       TP20R             PR_Parts_Library (48 37)               MR0
U1                        SI470X_20_QFN     PR_Parts_Library (26.9 56.9)           R90
X1                        4-SOJ             PR_Parts_Library (27.2 64.58)          R0

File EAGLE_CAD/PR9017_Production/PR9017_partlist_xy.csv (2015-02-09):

Part name | xpos | ypos
AMP | 36 | 8.1
ANT_MOUNT | 9.5 | 35
C01 | 29.01 | 59.6
C02 | 24.7 | 59.6
C03 | 30.24 | 58.03
C05 | 24.6 | 52.7
C08 | 34.2 | 51.7
C10 | 24.7 | 61.3
C11 | 29 | 61.3
C14 | 24.6 | 54
C20 | 41.9 | 7.1
C21 | 42.5 | 9.6
C22 | 39.4 | 12.3
C23 | 31.1 | 9.1
C24 | 31.1 | 10.3
C25 | 31.1 | 7.8
C32 | 43.6 | 51.7
C33 | 40.6 | 51.7
C40 | 45 | 14
D1 | 16.4 | 43.5
FB2 | 31.1 | 12.1
FB3 | 31.11 | 5.94
FET1 | 59.4 | 20.5
ISP | 43.8 | 64.2
JP5 | 35 | 53.5
JP6 | 35 | 16.5
JST_CONN | 24.2 | 9.4
L3 | 34.7 | 15.8
L01 | 22 | 53.2
L02 | 34.7 | 61.3
LED | 64.2 | 50
MARK1 | 17 | 9
MARK2 | 33 | 67
MARK3 | 65 | 35
MCU | 43.8 | 55.4
R1 | 60.5 | 35
R6 | 29.5 | 51.7
R02 | 29.5 | 53.1
R03 | 30.6 | 54.4
R04 | 34.8 | 54.4
R05 | 34.8 | 56.8
R07 | 34.8 | 55.6
R08 | 34.8 | 58
R20 | 38.7 | 4
R21 | 41.9 | 8.3
R22 | 39.4 | 10.9
R23 | 36 | 10.7
R24 | 36 | 5.7
R30 | 47.3 | 52
R31 | 62 | 50
R40 | 31.6 | 17.6
SPKR_PLACE | 35 | 35
SW1 | 52.8 | 59.9
TP1 | 10.6 | 44.6
TP2 | 60.5 | 35
TP3 | 60.5 | 30
TP4 | 37.9 | 17.7
TP5 | 37 | 61
TP6 | 30.3 | 15.2
TP7 | 28.8 | 2.7
TP8 | 50 | 61
TP9 | 53 | 61
TP10 | 50 | 64
TP11 | 37 | 67
TP12 | 37 | 64
TP13 | 39 | 68
TP14 | 66 | 24.5
TP15 | 66 | 45.5
TP16 | 53 | 27
TP17 | 48 | 33
U1 | 26.9 | 56.9
X1 | 27.2 | 64.58

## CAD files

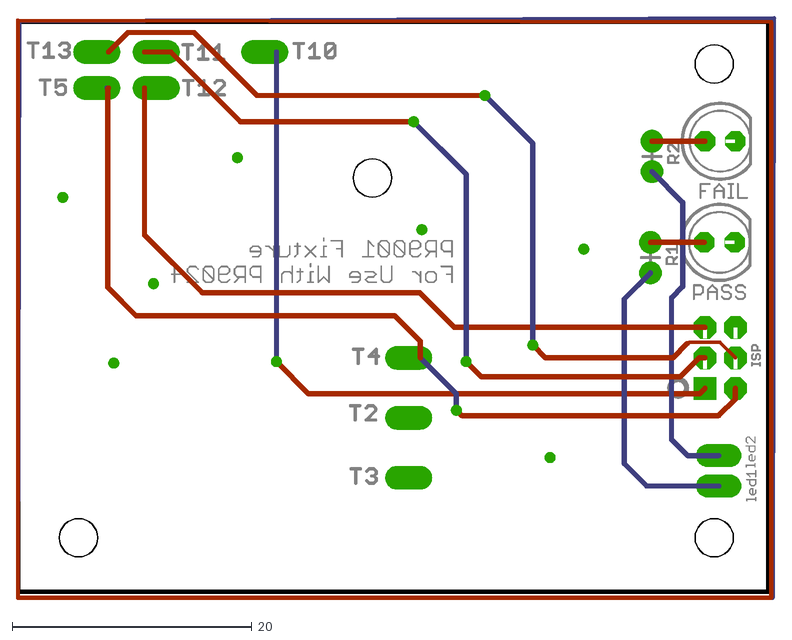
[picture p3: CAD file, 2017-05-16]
EAGLE_CAD/Test_Fixtures/PR9001/PR9001.dxf
63.4 x 48.6

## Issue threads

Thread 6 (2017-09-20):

fix audio pop

pencerw, 2017-09-20:
possibly by tying the FMIC's GPIO pin to shutdown on the amp, per @bigjosh's suggestion

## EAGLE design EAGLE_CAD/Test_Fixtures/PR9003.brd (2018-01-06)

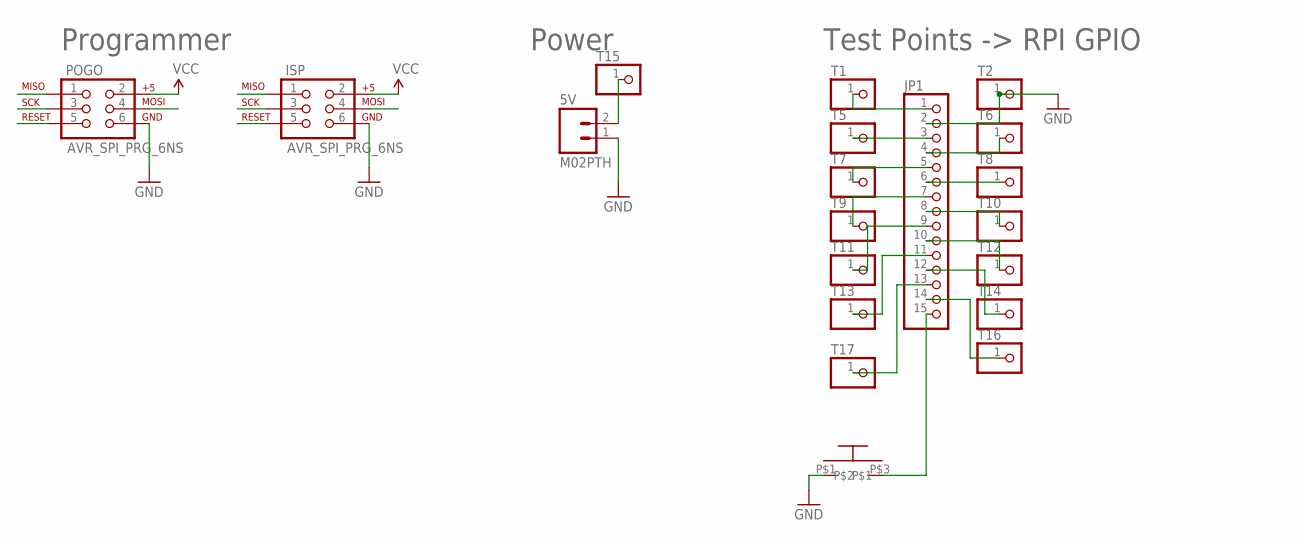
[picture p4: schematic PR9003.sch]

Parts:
5V: M02PTH; 1X02
ISP: AVR_SPI_PRG_6NS; 2X3-NS
JP1: PINHD-1X15; 1X15
POGO: AVR_SPI_PRG_6NS; 2X3-NS
T1, T2, T5, T6, T7, T8, T9, T10, T11, T12, T13, T14, T15, T16, T17: PINHD-1X1; 1X01
U$1: C&K_D6C_SWITCH

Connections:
GND: 5V.1, ISP.6, JP1.2, POGO.6, T2.1, U$1.P$1
MISO: ISP.1, POGO.1
MOSI: ISP.4, POGO.4
unnamed: JP1.1, T1.1
unnamed: JP1.3, T5.1
unnamed: JP1.4, T6.1
unnamed: JP1.5, T7.1
unnamed: JP1.6, T8.1
unnamed: JP1.7, T9.1
unnamed: JP1.8, T10.1
unnamed: JP1.9, T11.1
unnamed: JP1.10, T12.1
unnamed: JP1.11, T13.1
unnamed: JP1.12, T14.1
unnamed: 5V.2, T15.1
unnamed: JP1.14, T16.1
unnamed: JP1.13, T17.1
unnamed: JP1.15, U$1.P$3
RESET: ISP.5, POGO.5
SCK: ISP.3, POGO.3
VCC: ISP.2, POGO.2

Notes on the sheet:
Power
Test Points -> RPI GPIO
Programmer

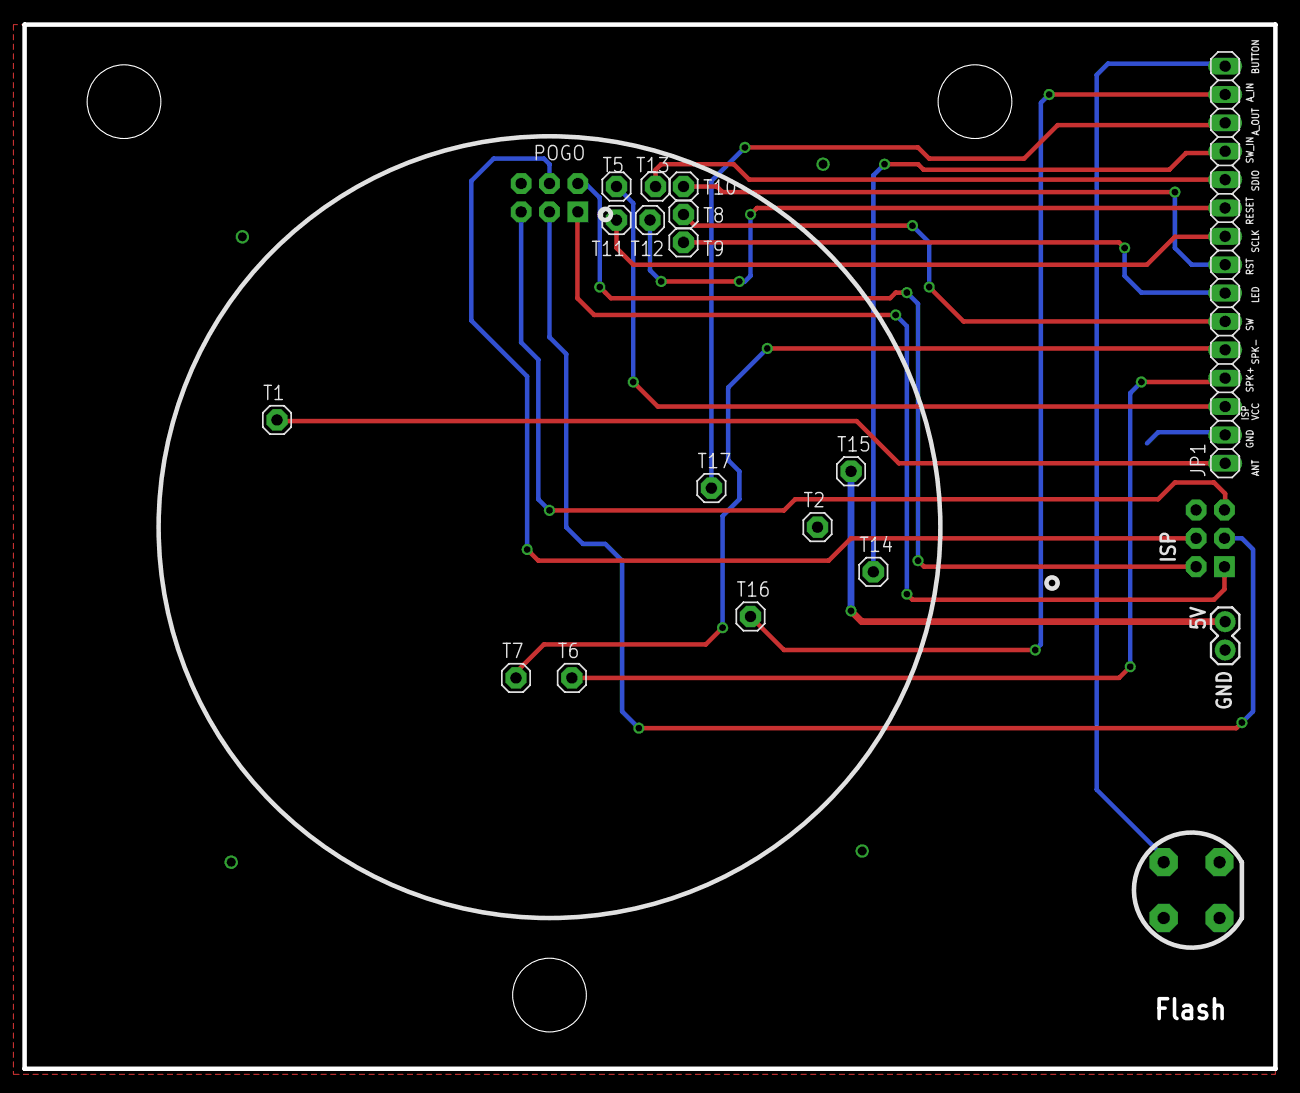
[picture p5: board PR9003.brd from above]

Board: 2 copper layers, 112.0 x 93.5 mm, 20 parts (1 on the bottom side), 21 nets.

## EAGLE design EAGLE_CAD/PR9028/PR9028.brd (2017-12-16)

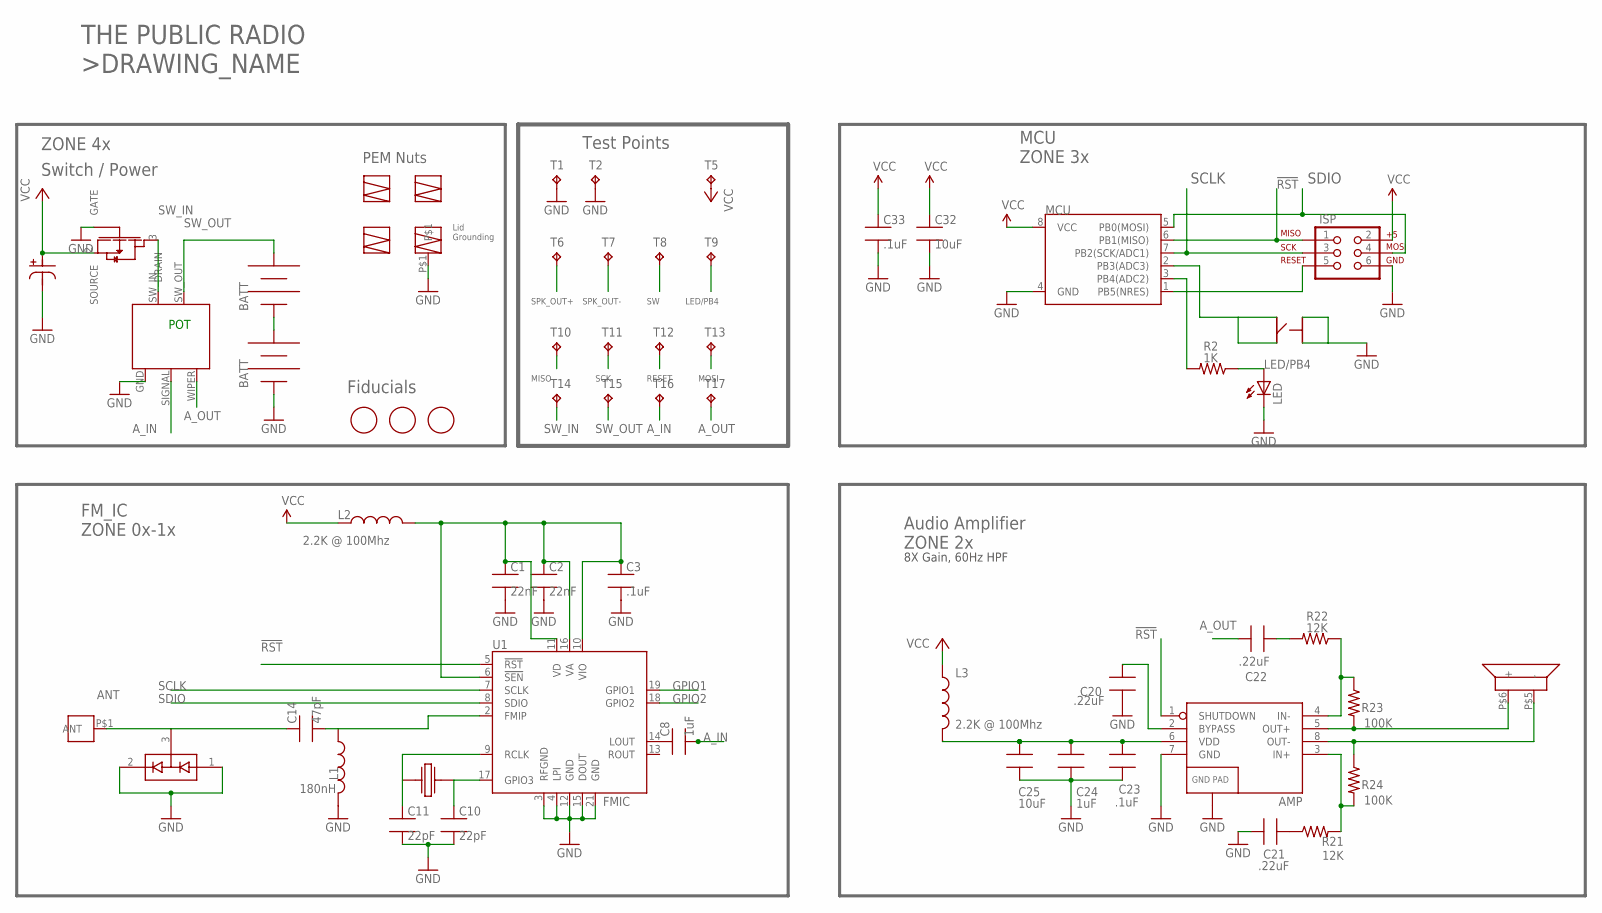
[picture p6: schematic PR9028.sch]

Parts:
AMP: TPA6203A1; 8-MSOP
ANT_MOUNT: PEM_M3_ANTENNA; MFG_PN Consigned
C1, C2: 22nF; 0603_CPL; VOLTAGE 16V; MFG_PN CL10B223KB8NNNC
C3, C23, C33: .1uF; 0603_CPL; VOLTAGE 16V; MFG_PN CL10B104KB8SFNC
C8, C24: 1uF; 0603_CPL; VOLTAGE 10V; MFG_PN CL10B105KP8NNNC
C10, C11: 22pF; 0603_CPL; VOLTAGE 50V; MFG_PN C1608C0G1H220J080AA
C14: 47pF; 0603_CPL; VOLTAGE 50V; MFG_PN CL10C470JB8NCNC
C20, C21, C22: .22uF; 0603_CPL; VOLTAGE 16V; MFG_PN C1608X7R1C224K080AC
C25, C32: 10uF; 0603_CPL; VOLTAGE 6.3V; MFG_PN CL10A106MQ8NNNC
C40: 220uF; NICHICON_UD_63; VOLTAGE 16V
D1: BAV99; SOT23_CPL; MFG_PN BAV99,215
FET1: AO3435; SOT23_CPL; MFG_PN AO3435
ISP: AVR_SPI_PRG_6NS; 2X3-NS; MFG_PN DNP
JP5, JP6: BK-92_MPD_AA_BATT_CLIP; BK92_AA_BATT; MFG_PN Consigned
L1: 180nH; 0805_ADAFRUIT; MFG_PN AISC-0805-R18J-T
L2, L3: 2.2K @ 100Mhz; 0603_CPL
LED: HSMC-C265_REVERSE_MOUNT_LED; HSMA-C265_REVERSE_MOUN_LED; MFG_PN HSMA-C265
MARK1, MARK2, MARK3: FIDUCIAL; FIDUCIAL_1MM
MCU: ATTINY45TINY45-20-SMT; 8-SOIC; MFG_PN ATTINY25-20SUR
R1: VOLUME_POTTAIWAN_ALPHA; RV170SF_SW_POT; MFG_PN Consigned
R2: 1K; 0603_CPL; MFG_PN RR0816P-102-D
R21, R22: 12K; 0603_CPL; MFG_PN RC0603FR-0712KL
R23, R24: 100K; 0603_CPL; MFG_PN ERJ-3EKF1003V
SPEAKER: PR2023_GROUND_UP_SPEAKER; MFG_PN Consigned
SPEAKER_PEM_1, SPEAKER_PEM_2, SPEAKER_PEM_4: PEM_M3_SPK; MFG_PN Consigned
SPEAKER_PEM_3: PEM_M3_SPK_GROUND; PEM_M3_SPK; MFG_PN Consigned
SW1: C&K_PTS645; C&K_PTS645_SMT
T1, T2, T5, T6, T7, T8, T9, T10, T11, T12, T13, T14, T15, T16, T17: TPTP20R; TP20R
U1: FMIC; SI470X_20_QFN; MFG_PN SI4702-C19-GMR
X1: ABS25XTAL; 4-SOJ

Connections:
!RST: AMP.1 (SHUTDOWN), ISP.1, MCU.6 (PB1(MISO)), T10.TP, U1.5 (!RST)
ANT: ANT_MOUNT.P$1, C14.1, D1.3 (COM)
A_IN: C8.2, R1.SIGNAL, T16.TP
A_OUT: C22.2, R1.WIPER, T17.TP
GND: AMP.7 (GND), AMP.9 (GND), C1.2, C2.2, C3.2, C10.2, C11.2, C20.1, C21.1, C23.2, C24.2, C25.2, C32.2, C33.2, C40.P$2, D1.1 (A1), D1.2 (C2), FET1.1 (GATE), ISP.6, JP6.NEG, JP6.NEG@2 (NEG), L1.2, LED.P$2 (GND), MCU.4 (GND), R1.GND, SPEAKER_PEM_3.P$1, SW1.P$1, SW1.P$2, T1.TP, T2.TP, U1.3 (RFGND), U1.4 (LPI), U1.12 (GND), U1.15 (DOUT), U1.21 (GND)
GPIO1: U1.19 (GPIO1)
GPIO2: U1.18 (GPIO2)
LED/PB4: MCU.3 (PB4(ADC2)), R2.2, T9.TP
unnamed: C11.1, U1.9 (RCLK), X1.P$1
unnamed: LED.P$1 (VCC), R2.1
unnamed: C22.1, R22.2
unnamed: AMP.6 (VDD), C23.1, C24.1, C25.1, L3.2
unnamed: AMP.3 (IN+), R21.2, R24.2
unnamed: C1.1, C2.1, C3.1, L2.2, U1.6 (!SEN), U1.10 (VIO), U1.11 (VD), U1.16 (VA)
unnamed: C8.1, U1.14 (LOUT)
unnamed: C10.1, U1.17 (GPIO3), X1.P$4
unnamed: AMP.2 (BYPASS), C20.2
unnamed: JP5.NEG, JP5.NEG@2 (NEG), JP6.POS, JP6.POS@2 (POS)
unnamed: AMP.4 (IN-), R22.1, R23.1
unnamed: C14.2, L1.1, U1.2 (FMIP)
unnamed: C21.2, R21.1
RESET: ISP.5, MCU.1 (PB5(NRES)), T12.TP
SCLK: ISP.3, MCU.7 (PB2(SCK/ADC1)), T11.TP, U1.7 (SCLK)
SDIO: ISP.4, MCU.5 (PB0(MOSI)), T13.TP, U1.8 (SDIO)
SPK_OUT+: AMP.5 (OUT+), R23.2, SPEAKER.P$6 (+), T6.TP
SPK_OUT-: AMP.8 (OUT-), R24.1, SPEAKER.P$5 (-), T7.TP
SW: MCU.2 (PB3(ADC3)), SW1.P$3, SW1.P$4, T8.TP
SW_IN: FET1.3 (DRAIN), R1.SW_IN, T14.TP
SW_OUT: JP5.POS, JP5.POS@2 (POS), R1.SW_OUT, T15.TP
VCC: C32.1, C33.1, C40.P$1, FET1.2 (SOURCE), ISP.2, L2.1, L3.1, MCU.8 (VCC), T5.TP

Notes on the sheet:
POT
FM_IC ZONE 0x-1x
Switch / Power
Lid Grounding
Audio Amplifier ZONE 2x
MCU ZONE 3x
THE PUBLIC RADIO >DRAWING_NAME
Fiducials
Test Points
MISO
SCK
RESET
MOSI
8X Gain, 60Hz HPF
ZONE 4x
PEM Nuts

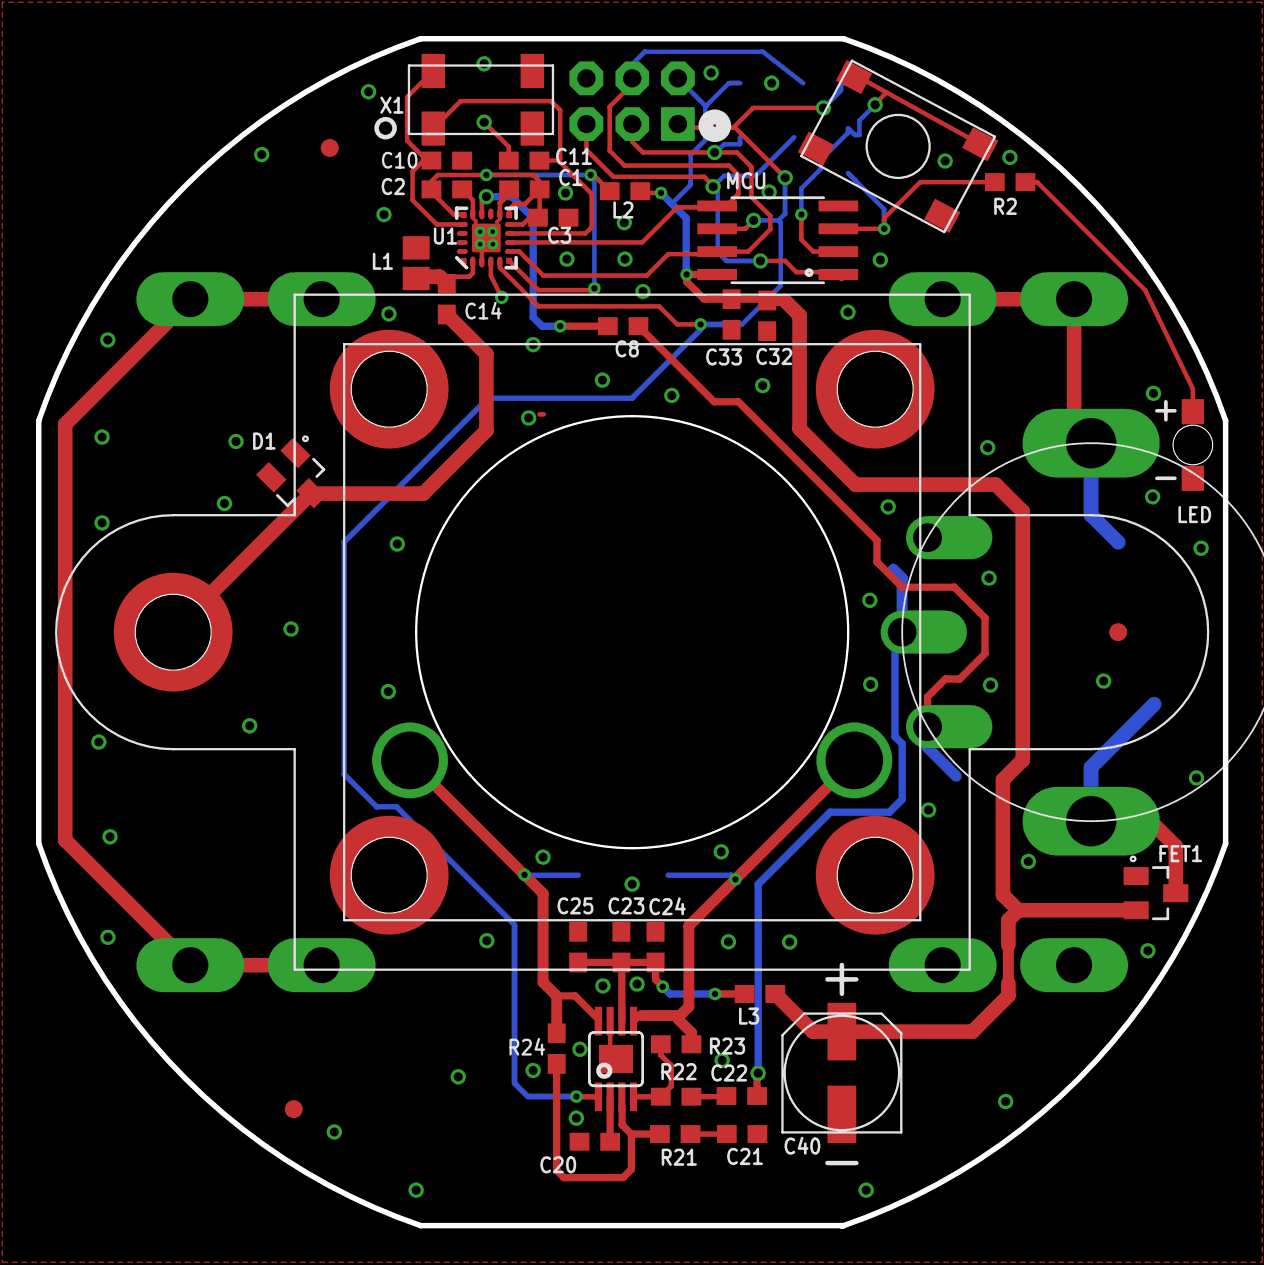
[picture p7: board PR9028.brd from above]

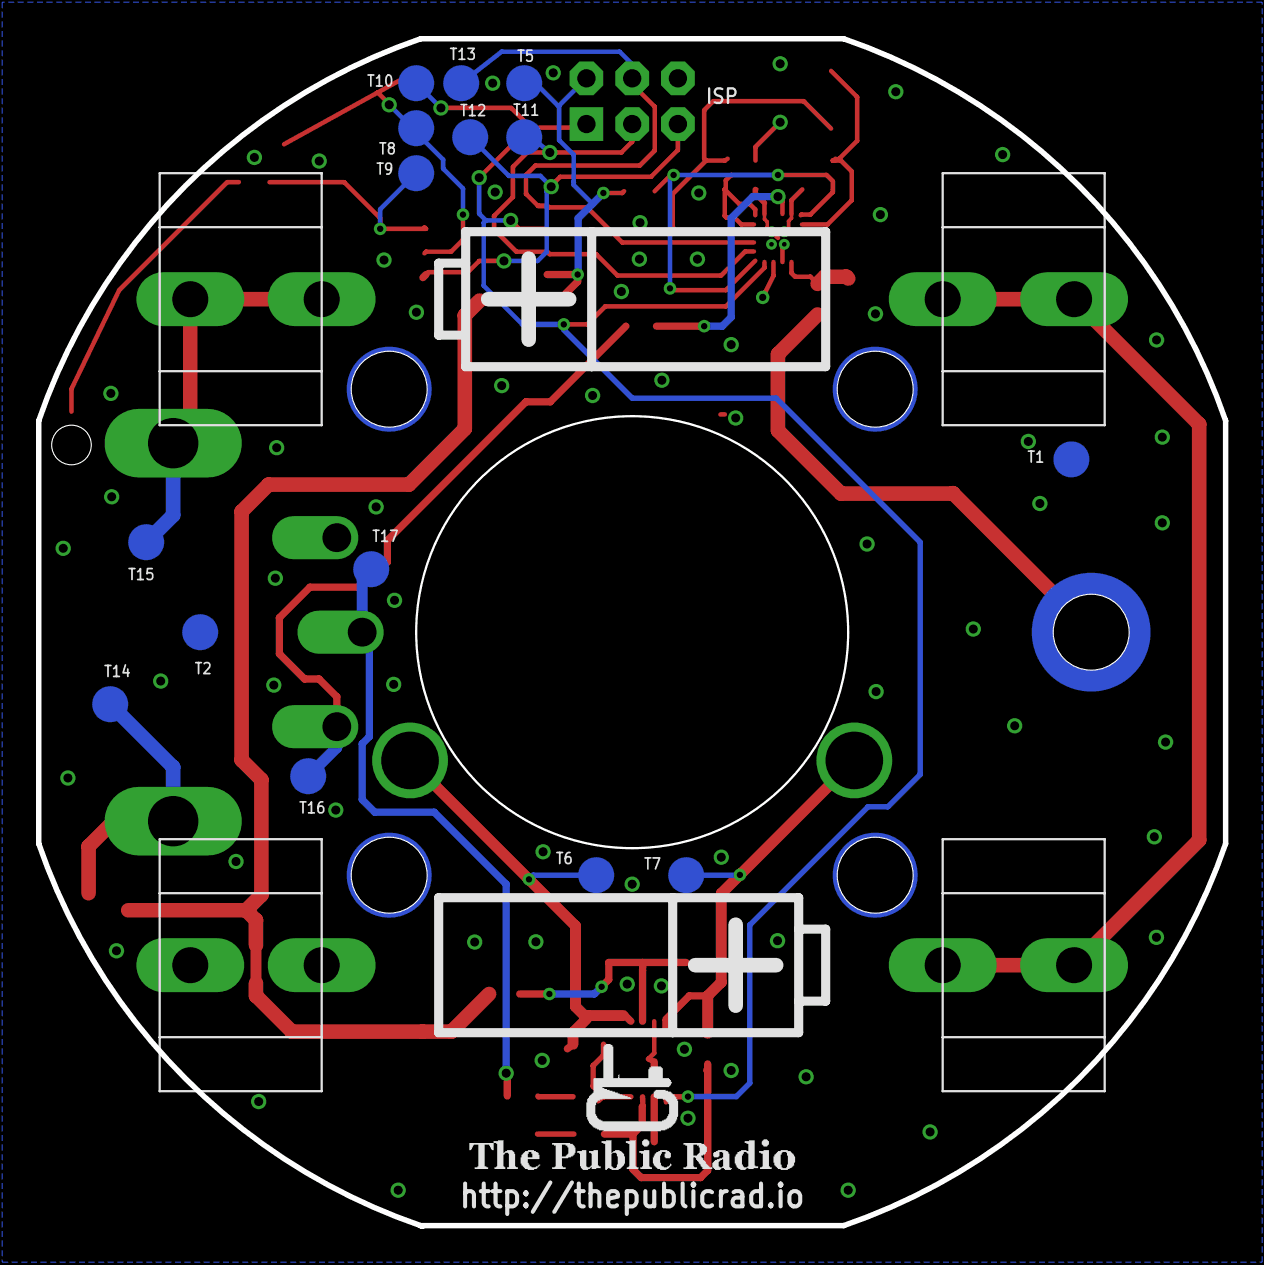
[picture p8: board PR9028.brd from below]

Board: 2 copper layers, 65.9 x 65.9 mm, 61 parts (19 on the bottom side), 28 nets.

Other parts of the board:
U$2: PR_LOGO_2.0

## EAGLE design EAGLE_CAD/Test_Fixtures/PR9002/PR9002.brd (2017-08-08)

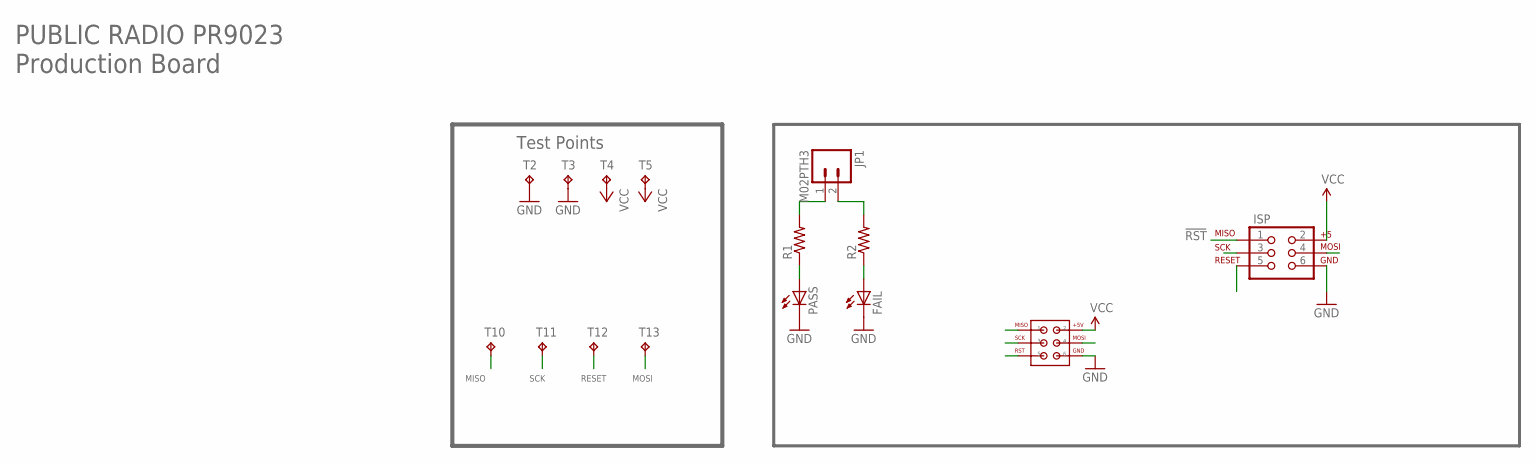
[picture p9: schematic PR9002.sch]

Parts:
FAIL: LED5MM
ISP: AVR_SPI_PRG_6NS; 2X3-NS
JP1: M02PTH3; 1X02_LONGPADS
PASS: LED5MM
R1, R2: RESISTORPTH-1/4W-VERT; AXIAL-0.1
T2, T3, T4, T5, T10, T11, T12, T13: PR9001_TESTPOINT
U$1: ISP_POGOBED_S19_501

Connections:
!RST: ISP.1, T10.P$1, U$1.P$1
GND: FAIL.K (C), ISP.6, PASS.K (C), T2.P$1, T3.P$1, U$1.P$6
unnamed: JP1.2, R2.P$2 (2)
unnamed: PASS.A, R1.P$1 (1)
unnamed: JP1.1, R1.P$2 (2)
unnamed: FAIL.A, R2.P$1 (1)
RESET: ISP.5, T12.P$1, U$1.P$5
SCLK: ISP.3, T11.P$1, U$1.P$3
SDIO: ISP.4, T13.P$1, U$1.P$4
VCC: ISP.2, T4.P$1, T5.P$1, U$1.P$2

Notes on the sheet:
PUBLIC RADIO PR9023 Production Board
Test Points
MISO
SCK
RESET
MOSI

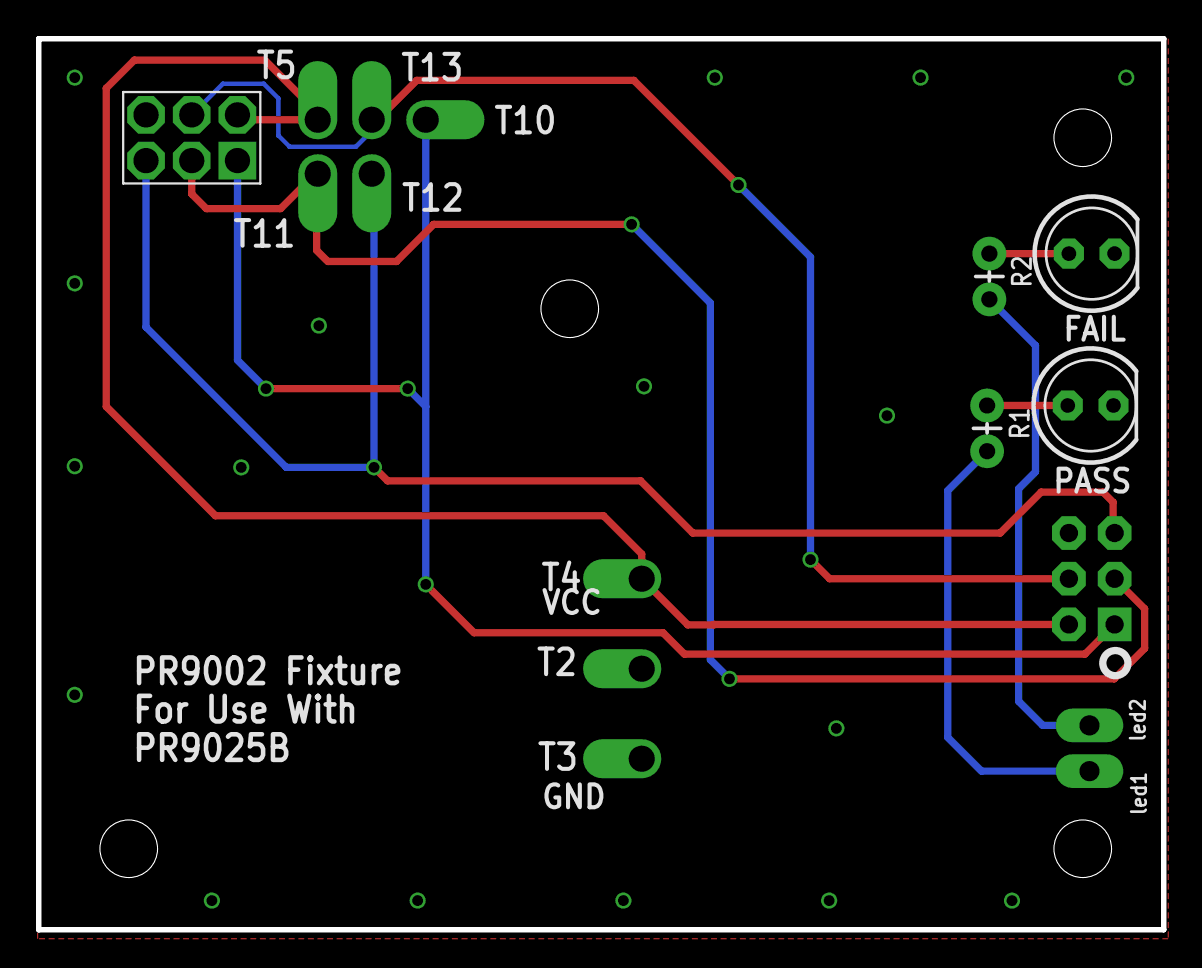
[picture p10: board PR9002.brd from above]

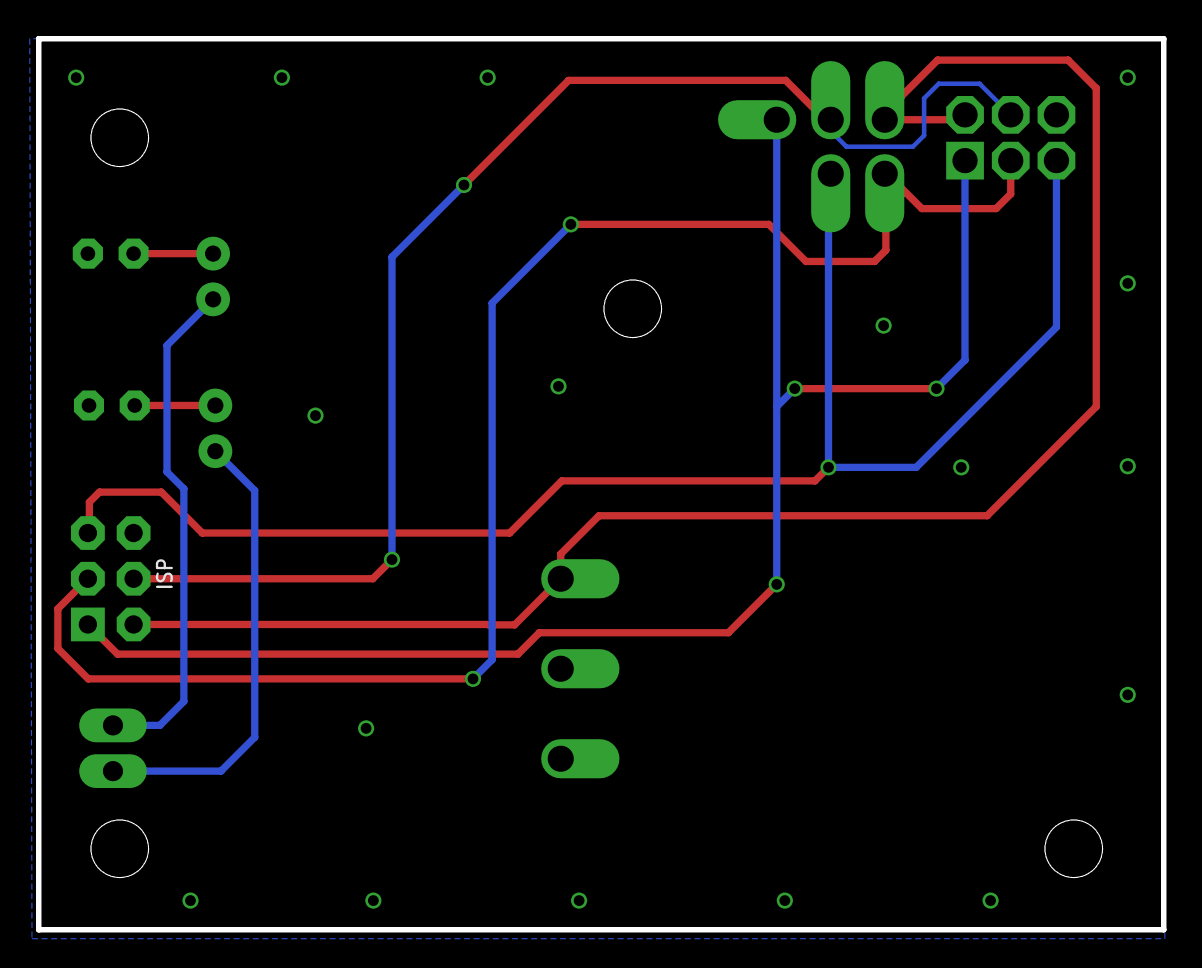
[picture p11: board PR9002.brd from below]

Board: 2 copper layers, 62.5 x 49.5 mm, 15 parts (8 on the bottom side), 10 nets.

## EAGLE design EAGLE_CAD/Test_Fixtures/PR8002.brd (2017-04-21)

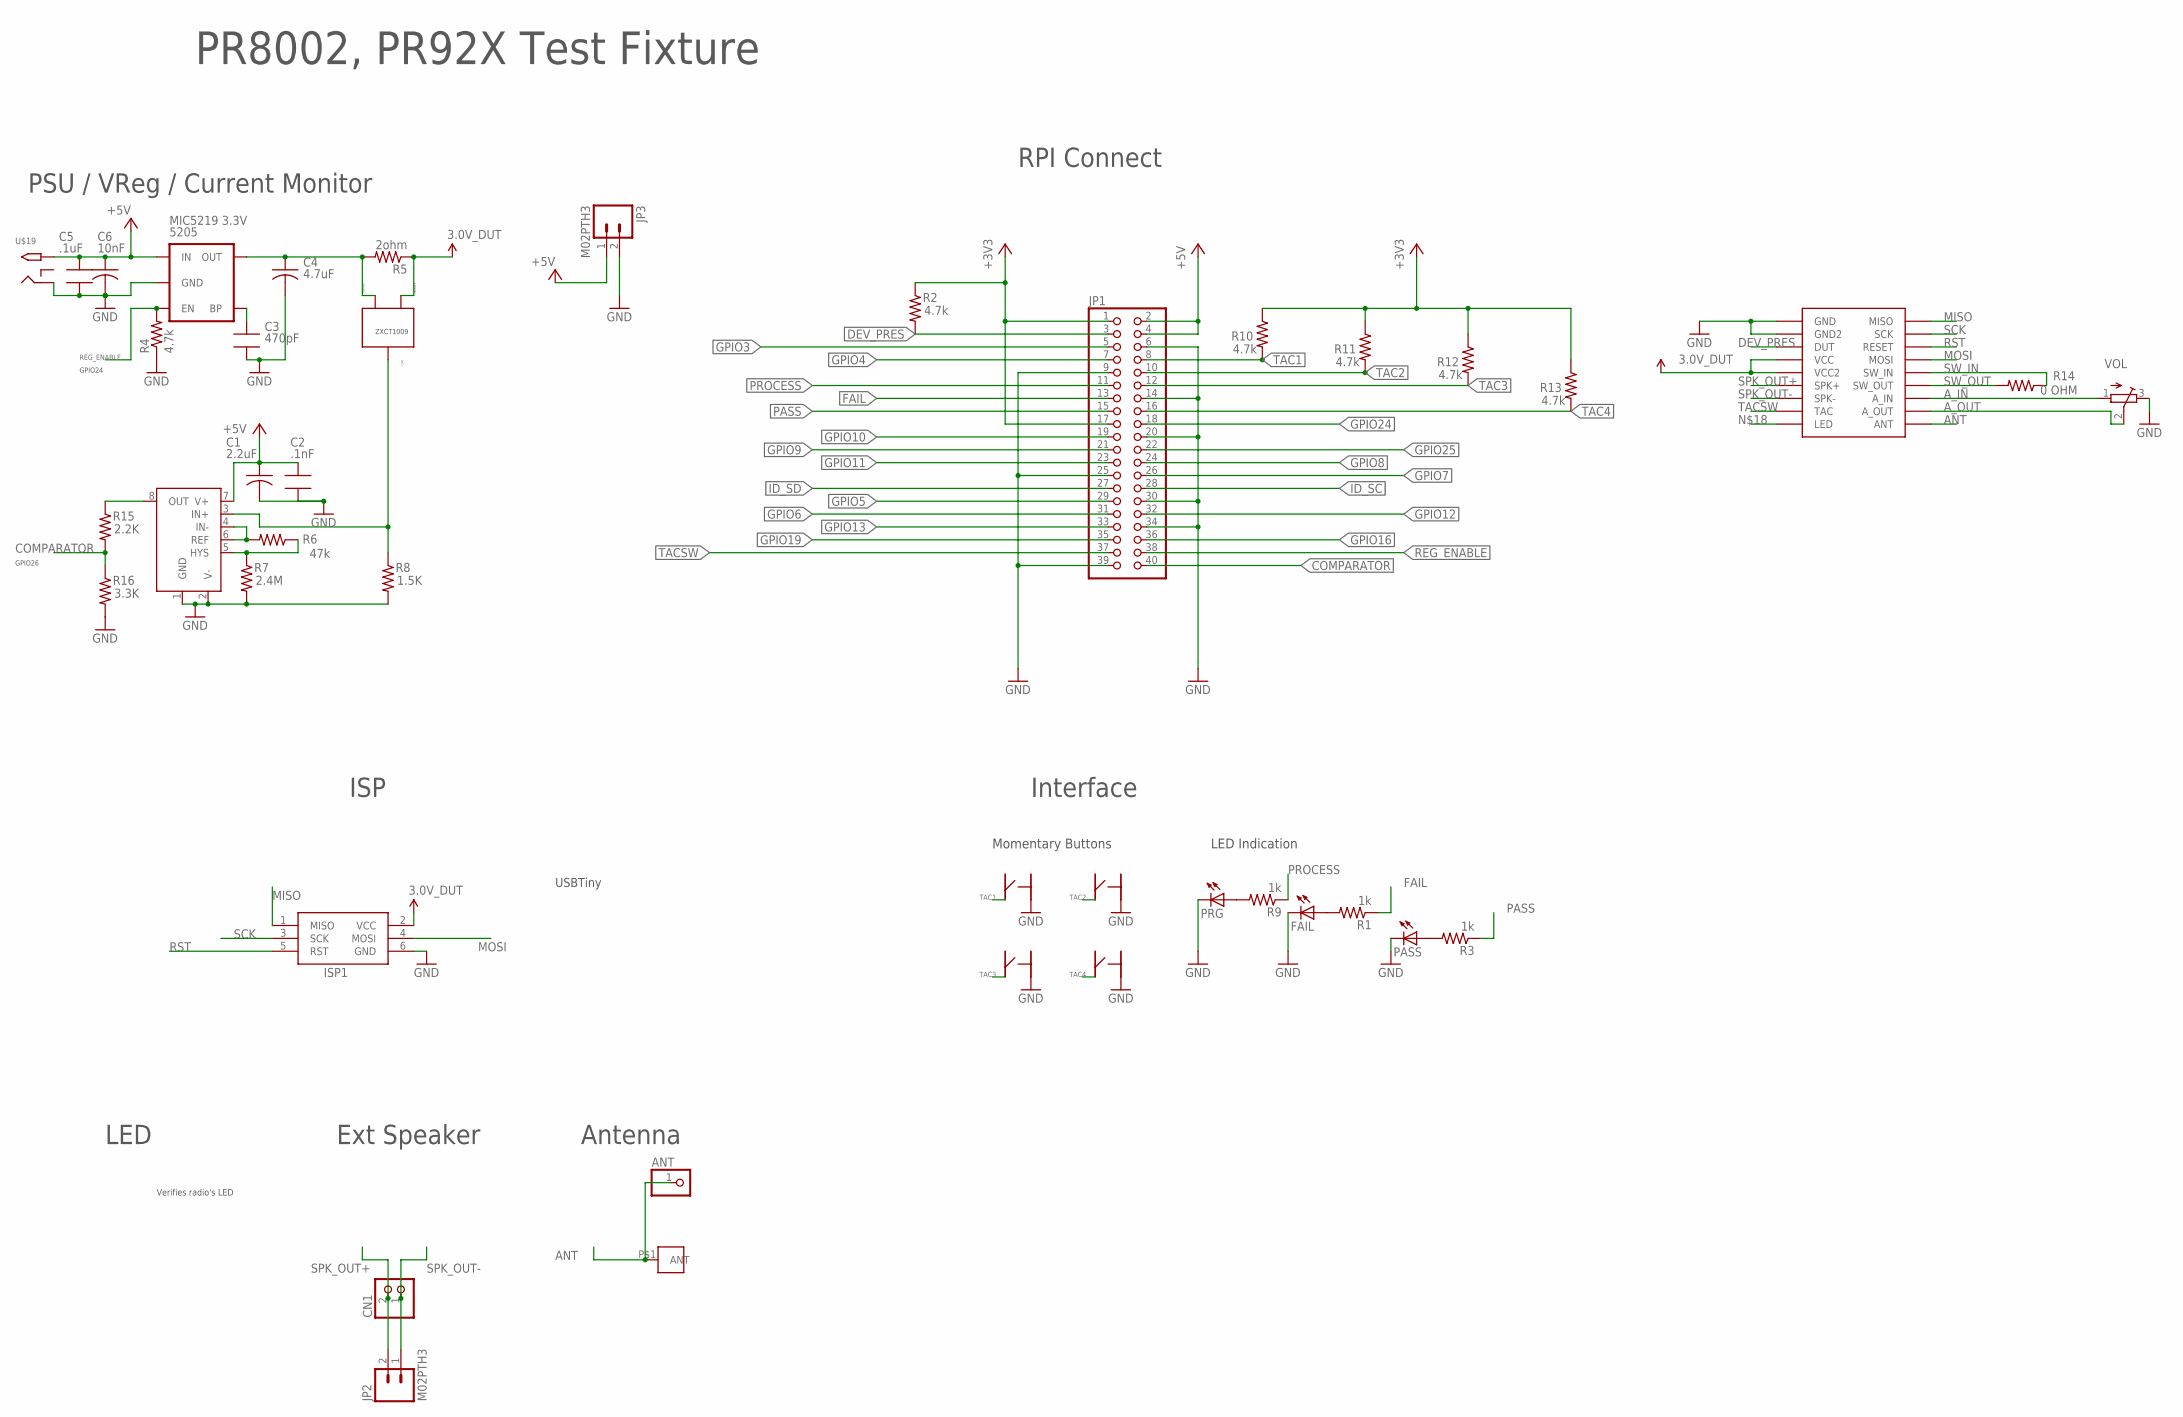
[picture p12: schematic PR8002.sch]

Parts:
5205: MIC5219 3.3V; SOT23-5
ANT: PINHD-1X1; 1X01
C1: 2.2uF; C0805
C2: .1nF; 0805_ADAFRUIT
C3: 470pF; 0805_ADAFRUIT
C4: 4.7uF; C0805
C5: .1uF; 0805_ADAFRUIT
C6: 10nF; C0805
CN1: JST_2PIN-SMT-RA; JST-B2B-PH-SM4-TB
FAIL: LEDCHIP-LED0805; CHIP-LED0805
ISP1: AVRISP-6; AVRISP
J1: M3_SCREW_POST; M3_BOLT_HOLE
JP1: PINHD-2X20; 2X20
JP2, JP3: M02PTH3; 1X02_LONGPADS
PASS: LEDCHIP-LED0805; CHIP-LED0805
PRG: LEDCHIP-LED0805; CHIP-LED0805
R1, R3, R9: 1k; 0805_ADAFRUIT
R2, R4, R10, R11, R12, R13: 4.7k; 0805_ADAFRUIT
R5: 2ohm; 0805_ADAFRUIT
R6: 47k; 0805_ADAFRUIT
R7: 2.4M; 0805_ADAFRUIT
R8: 1.5K; 0805_ADAFRUIT
R14: 0 OHM; 0805_ADAFRUIT
R15: 2.2K; 0805_ADAFRUIT
R16: 3.3K; 0805_ADAFRUIT
TSM931: TSM931; MSOP8
U$19: 2.1MMJACKTHM; PJ-102A
U$20, U$22, U$23, U$24: C&K_PTS645; C&K_PTS645_SMT
U$26: PR9020_TESTPOINTS
VOL: TRIMPOTTC33X; TC33X
ZXCT: ZXCT1009; SOT23

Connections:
3.3V: ISP1.2 (VCC), R5.1, U$26.P$4 (VCC), U$26.P$5 (VCC2), ZXCT.1 (VSENSE+)
+3V3: JP1.1, JP1.17, R2.1, R10.1, R11.1, R12.1, R13.1
+5V: 5205.1 (IN), C1.1, C2.1, C5.1, C6.1, JP1.2, JP1.4, JP3.1, TSM931.7 (V+), U$19.TIP
ANT: ANT.1, J1.P$1, U$26.P$18 (ANT)
A_IN: U$26.P$16 (A_IN), VOL.1 (A)
A_OUT: U$26.P$17 (A_OUT), VOL.2 (S)
COMPARATOR: JP1.40, R15.2, R16.1
DEV_PRES: JP1.3, R2.2, U$26.P$3 (DUT)
FAIL: JP1.13, R1.1
GND: 5205.2 (GND), C1.2, C2.2, C3.2, C4.2, C5.2, C6.2, FAIL.C, ISP1.6 (GND), JP1.6, JP1.9, JP1.14, JP1.20, JP1.25, JP1.30, JP1.34, JP1.39, JP3.2, PASS.C, PRG.C, R4.1, R7.2, R8.2, R16.2, TSM931.1 (GND), TSM931.2 (V-), U$19.RING, U$20.P$2, U$22.P$2, U$23.P$2, U$24.P$2, U$26.P$1 (GND), U$26.P$2 (GND2), VOL.3 (E)
GPIO3: JP1.5
GPIO4: JP1.7
GPIO5: JP1.29
GPIO6: JP1.31
GPIO7: JP1.26
GPIO8: JP1.24
GPIO9: JP1.21
GPIO10: JP1.19
GPIO11: JP1.23
GPIO12: JP1.32
GPIO13: JP1.33
GPIO16: JP1.36
GPIO19: JP1.35
GPIO24: JP1.18
GPIO25: JP1.22
ID_SC: JP1.28
ID_SD: JP1.27
MISO: ISP1.1 (MISO), U$26.P$10 (MISO)
MOSI: ISP1.4 (MOSI), U$26.P$13 (MOSI)
unnamed: R6.2, TSM931.4 (IN-), TSM931.6 (REF)
unnamed: PRG.A, R9.2
unnamed: FAIL.A, R1.2
unnamed: PASS.A, R3.2
unnamed: R15.1, TSM931.8 (OUT)
unnamed: R8.1, TSM931.3 (IN+), ZXCT.3 (IOUT)
unnamed: 5205.4 (BP), C3.1
unnamed: 5205.5 (OUT), C4.1, R5.2, ZXCT.2 (VSENSE-)
unnamed: R6.1, R7.1, TSM931.5 (HYS)
PASS: JP1.15, R3.1
PROCESS: JP1.11, R9.1
REG_ENABLE: 5205.3 (EN), JP1.38, R4.2
RST: ISP1.5 (RST), U$26.P$12 (RESET)
SCK: ISP1.3 (SCK), U$26.P$11 (SCK)
SPK_OUT+: CN1.2 (1), JP2.2, U$26.P$6 (SPK+)
SPK_OUT-: CN1.1 (2), JP2.1, U$26.P$7 (SPK-)
SW_IN: R14.2, U$26.P$14 (SW_IN)
SW_OUT: R14.1, U$26.P$15 (SW_OUT)
TAC1: JP1.8, R10.2, U$20.P$4
TAC2: JP1.10, R11.2, U$23.P$4
TAC3: JP1.12, R12.2, U$22.P$4
TAC4: JP1.16, R13.2, U$24.P$4
TACSW: JP1.37, U$26.P$8 (TAC)

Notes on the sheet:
Antenna
Ext Speaker
LED
ISP
PSU / VReg / Current Monitor
RPI Connect
PR8002, PR92X Test Fixture
Verifies radio's LED
Interface
GPIO24
GPIO26
ZXCT1009
USBTiny
Momentary Buttons
LED Indication

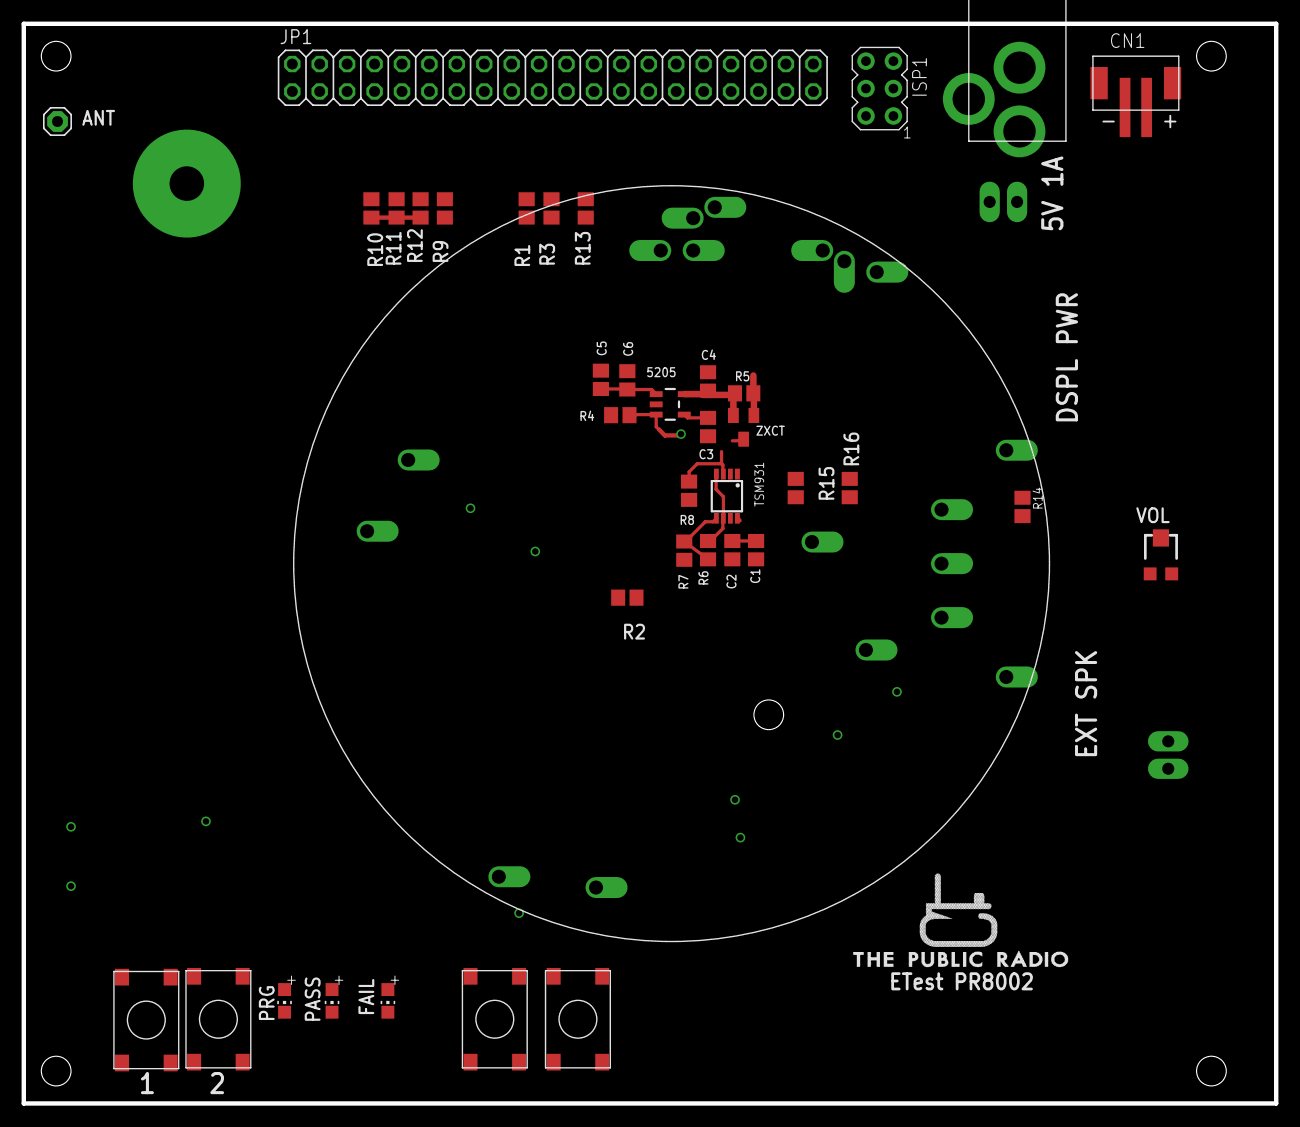
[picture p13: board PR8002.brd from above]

Board: 2 copper layers, 116.0 x 100.0 mm, 43 parts (0 on the bottom side), 35 nets.

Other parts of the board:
U$1: PR_LOGO

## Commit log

2014-01-22 Added existing hardware
    PR5001 is Zach’s original breakout board shield. PR5002 is my first
    attempt at pro mini + discrete components; PR5003 is the current design.
    [PR5001 Mini Breakout Shield.brd, PR5001 Mini Breakout Shield.sch, PR5002-S.brd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]
2014-01-27 part ordered from OSHPark ixjqvHyB
    few revisions:
    moved a bunch of shit away from the antenna
    removed ground planes away from antenna
    this commit has the version of PR5003 that we actually ordered from
    OSHPark on 2014.01.27
    [PR5003.brd]
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2014-02-05 Copied PR5005, started PR5006
    PR5006 includes accurate packages & locations of pot, speaker, and
    antenna connector. I also locked down the amp and started some of the
    other shit.
    [PR5006.brd, PR5006.sch]
2014-02-05 added archive directory
    moved a bunch of older files to an archive directory.
    [PR5001 Mini Breakout Shield.brd, PR5001 Mini Breakout Shield.sch, PR5002-S.brd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]
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2014-02-05 Updated Layout
    Re-ran signal and pwr lines. Ran DRC from PCB cart and corrected
    errors. Errors still exist on the ERC
2014-02-05 Updated Layout
    Fixed Si4831 package. ERC and DRC check out
    [PR5006.brd, PR5006.sch]
2014-02-06 Revised BRD only
    Revised BRD during google hangout.
    After Z got off the phone I played with the speaker traces a bit and a
    few other minor things, but nothing big.
    [PR5006.brd]
2014-02-06 NO DRC ERRORS!
    I rewired a few things - moved stuff around on the tuning circuit,
    moved the FM power trace a touch. I also did a cute thing with the
    power trace on the left side of the board, and turned the antenna LC
    circuit to 45*, and redrew the antenna restrict so that it’s all
    smooth.
    [PR5006.brd]
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2014-02-10 more stuff post todd
    new thru hole cap on tune circuit, different restrict zone around
    antenna… etc
    [PR5006.brd, PR5006.sch]
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2014-03-04 v1.4 initial commit
    revised trimpot package. revised much layout stuff. added BMP.
    [PR5006.brd, PR5006.sch]
2014-05-16 New Board Layout
    Made some of the edits based on the workflowy feature request list.
    [PR5007.brd, PR5007.sch]
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2014-05-17 Updated 5007
    Update from 5.14. speaker wires no longer crossing
    [PR5007.brd, PR5007.sch]
2014-05-17 changes from the phone
    did pad changes for the trimpot and pot
    moved a couple components to start bigger redesign, nothing permanent
    [PR5007.brd, PR5007.sch]
2014-05-22 Updates Post-Phone Call
    Added C18,C19,C20 in parallel with existing decoupling caps.
    Reworked routing around FM IC and Amp
    Added coupling caps and resistors for L+R out.
    [PR5001 Mini Breakout Shield.brd, PR5001 Mini Breakout Shield.sch, PR5002-S.brd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]
2014-05-28 Misc wishlist edits
    made LED thru hole.
    added restrict on battery clips
    moved vcc traces to top layer to avoid bottom ground plane at battery
    clips
    misc re-routing chages
    [PR5007.brd, PR5007.sch]
2014-06-06 More Feature Request Updates
    Added reverse polarity protection with p-channel mosfet, removed 1K
    summing resistors for L&R mix, moved RF IC audio output to the bottom
    layer, cleaned up part names and increased size for better print
    resolution, added board # and station # markings on the bottom layer.
    [PR5007.brd, PR5007.sch]
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2014-06-08 bigger redesign
    updated si4831 package; updated pot package; moved a bunch of stuff
    around
    [PR5007.brd, PR5007.sch]
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2014-06-15 more wish list
    swapped LED back to SMT. added headers for trimpot adjustment. redid
    layout all over.
    [PR5007.brd, PR5007.sch]
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2014-06-28 sch update + reset pin screwup
    major update to the sch - cleaned it up significantly
    also fixed screwup at the reset pin, which was a bug in pr5007
    some small brd changes too, mostly around the trimpot
    [PR5008.brd, PR5008.sch]
2014-09-08 Single Sided PCB
    Routed signal wires to be on the top plane with 3 (small) exceptions.
    [PR5009.brd, PR5009.sch]
2014-09-12 Updates and Fixes
    Small changes, clearing Osh Park design rules
    [PR5008.brd, PR5008.sch, PR5009.brd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]
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2014-11-25 Schematics Updates
    PR9010 is a new schematic for the public radio, using the si4702 and
    attiny85
    [PR5008.sch, PR9010.sch]
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2014-12-02 fixed prefixes
    [PR9010.brd, PR9010.sch]
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2014-12-06 grid fix
    grid fix
    [PR9010.brd, PR9010.sch]
2014-12-06 fixed most of the .sch grid issues
    but not any of the electrical connection lines
    [PR9010.sch]
2014-12-06 fixed all but one grid issue
    i don’t have the library for SI233DDS, but everything else should be
    kosher.
    [PR9010.brd, PR9010.sch]
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2014-12-13 Revert 4030fd6..8fbab64
    This rolls back to commit 4030fd6ea573634c9f94773de6c061aaf5ef7890.
    [PR9011.brd, PR9011.sch]
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2014-12-14 Updated Dev Board Layout
    Finished routing
    Added variable inductor
    Removed VCC from FM Headers
    Connected I2C pullup resistors to local FMIC VCC Line
    [PR9011.brd, PR9011.sch]
2014-12-15 Tweak layout, especially around the receiver IC, move ferrite bead over to Sparkfun 0805 footprint.
    Make most traces that don't need to be > 10mil, 10mil.
    Add top groundplane and via stitching.
    [PR9011.brd, PR9011.sch]
2014-12-15 Increase spacing on RF traces, and fix/approve DRC violations.
    Add antenna net and add 50mil of clearance around those traces, approve all the DRC violations that result.
    Fixup a handful of other DRC violations, some min-spacing violations.
    Approve all the restricted violations that are OK.
    [PR9011.brd, PR9011.sch]
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2014-12-20 changed speaker to JST
    added screw holes, removed pads on speaker. re-routed a couple of
    traces.
    [PR9011.brd, PR9011.sch]
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2014-12-21 ORGANIZED
    Did a few organizational things:
    *Added a subdirectory called EAGLE_CAD, and moved all .brd and .sch
    files there
    *Added a directory called EAGLE_lbr, and moved PR_Parts_Library (from
    the EAGLE_Libraries repo, which i’ll now delete) there
    *Added a directory called Production_files, and moved Gerber & Drill
    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
    [DRILEGEND.CFG, PR5009.brd, PR5009.sch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]
2014-12-21 Updated parts to new library file
    The Speaker, batteries, antenna screw hole, and potentiometer were all
    on a library on my local disc. I went through and replaced them all
    with the same parts from the new EAGLE_lbr/PR_Parts_Library library.
    [PR9011.brd, PR9011.sch]
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2015-01-05 Updated layout for next prototype
    PR9013 is essentially 9012 shrunk down onto the 70mm circular board.
    [PR9012.brd, PR9012.sch, PR9013.brd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]
2015-01-06 Some significant fixes & changes
    So i started by looking at the alignment of the board, speaker, pot &
    antenna. it turns out these were all a bit wacky - all laid out at
    different grid spacings and none of them consistent. the alignment of
    all was off relative to one another, and the board itself was just at
    some arbitrary location. so:
    i moved the whole board so that it’s centered at 35mm x 35mm
    moved the speaker so it’s centered at 35mm x 35mm
    moved the antenna and pot so they’re centered at 35mm (Ydim) and are
    each 25.5mm from centerline in the Xdim
    moved the batteries so that they’re centered at 35mm (Xdim) and each
    18.5mm from centerline in the Ydim
    then i:
    added a wire for th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
    [PR9013.brd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]
2015-01-11 moved some traces
    redid left battery trace
    redid the traces that were violating brestrict near the speaker
    moved the lid connection off the board - think we’ll prob move that to
    the speaker screws
    moved other traces in small ways
    [PR9012.brd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]
2015-01-12 Updated Parts
    Added the C&K part to PR Parts Library and updated PR9013 to include
    this part.
    [PR9013.brd, PR9013.sch]
2015-01-13 added package variant for speaker
    …and replaced the speaker with the variant. this one has no cutout,
    just a restrict on both top and bottom layers.
    [PR9013.brd, PR9013.sch]
2015-01-13 reverted back to original speaker
    [PR9013.brd]
2015-01-15 New Layout and Updated Packages
    -Updated the package for:
    o Tactile Switch
    o Decoupling Cap, C1
    o Xtal
    -Routed Amp, & MCU.
    Note:
    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
    [PR9013.brd, PR9013.sch]
2015-01-16 Updated SCH and Layout
    -Test Points Added
    To do:
    o double check locations for errors / conflicts
    o check pad size 1.4 mm big enough?, to big?
    -Flattened PCB for alignment
    -Changed Xtal package
    -Updated PR_Parts_Lib
    [PR9013.brd, PR9013.sch]
2015-01-16 layout & package changes
    updated a bunch (not all) packages to 0402. crammed everything in more
    compactly throughout.
    there’s still some sketchy stuff here but it’s not all bad :)
    [PR9013.brd, PR9013.sch]
2015-01-17 Updated SCH and Layout
    Changed some 0603 to 0402
    Changed some 0805 to 0402
    Connected a few traces near the amp
    [PR9013.brd, PR9013.sch]
2015-01-17 rearranged some stuff
    rearranged the bottom (amp) a bit so that the vcc and audio traces stay
    out of the battery area. other small changes.
    [PR9013.brd]
2015-01-17 more routing changes
    cleaned up amp section a bunch. feeling good about it.
    also changed a bunch of packages down to 0402
    and
    re-routed the AVR area a bunch.
    [PR9013.brd, PR9013.sch]
2015-01-17 saved a copy as pr9014
    and then dragged the FM section back down onto the board. still needs
    some work, plus Andy gets to go through and tell me where i’m wrong :)
    [PR9014.brd, PR9014.sch]
2015-01-17 Updated Library
    Added AO3435, (Fet for reverse polarity) to the library and replaced it
    in the sch and layout.
    [PR9014.brd, PR9014.sch]
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2015-01-19 bunch of changes
    couple library updates, the most notable of which is the button
    footprint
    then
    a bunch of layout edits
    mostly in response to andy’s feedback
    [PR9014.brd, PR9014.sch]
2015-01-19 minor ish changes
    relative to my last commit, at least
    one thing that mattered a little is that i changed the XTAL package -
    it was off a bit.
    [PR9014.brd, PR9014.sch]
2015-01-19 bunch of routing stuff
    and made the test points larger
    pretty close to being released for this round
    [PR9014.brd, PR9014.sch]
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2015-01-20 Updated Layout
    Fixed a few things, including some notes from Andy.
    Todo: change gnu pad connection on speaker screw
    [PR9014.brd, PR9014.sch]
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2015-01-20 Updated layout
    Changed drill sizes to match worthington’s min drill
    Updated Trestricts under the FM IC to fix distortion
    Added Bitmap PR drawing
    Added design version #
    [PR9014.brd]
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2015-01-22 okay, now we're good i think
    copied R_US over to PR_Parts_Library. Then added a new package variant
    and connected it with my c0402 package (created from Chris’s email).
    Then went into the .brd and replaced C17 with my new part. Seems to
    work.
    [PR9015.brd, PR9015.sch]
2015-01-22 Revert cea9e40..4e97d22
    This rolls back to commit cea9e40d509ff5bb8dd7e4369702d55ec1f1bc0f.
    [PR9015.brd, PR9015.sch]
2015-01-22 more c0402 changes
    and i swapped out c13 and it works
    [PR9015.brd, PR9015.sch]
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2015-02-04 PR9017
    Amp Fixes
    [PR9017.brd, PR9017.sch]
2015-02-07 small amp changes
    ripped up a few things.
    the test pads on the speaker were at the wrong point (on the sch) so i
    fixed that.
    then rerouted most of the amp section. don’t love it, but it’s a start.
    [PR9017.brd, PR9017.sch]
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2015-02-08 okay, woah
    i spent a *ton* of time going through the partlist & BOM. at this point
    basically everything in the circuit is from our PR_Parts_Library. i
    also simplified & improved the package names, descriptions, etc. and i
    gave all the passives 0603 footprints that came from the Common Parts
    Library.
    big thing: the values @ manufacturer part numbers. all of our parts
    have a custom attribute called “MFG_PN”. we should go through EVERY
    PART ON OUR SCHEMATIC and put actual manufacturer part numbers in those
    fields. i did this for all the parts that seemed critical, but i didn’t
    touch passives at all.
    there’s also some other stuff that will matter on the BOM/partlist
    side, but it’s pr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
    [PR9017.brd, PR9017.sch]
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2015-02-08 updated all part number etc
    part number
    added attributes for tolerance, voltage, power, etc
    re routed FMIC per AN383
    [PR9017.brd, PR9017.sch]
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2015-02-14 9018 & PRTF01
    9018 updated BOM and beginning layout & schematic of the PRXX test
    fixture
    [PR9017.brd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]
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2015-02-19 Very very small changes to layout
    Deleted a few vias that seemed problematic.
    [PRTF02.brd, PRTF02.sch]
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2015-02-26 Test fixture updates
    Initial schematic of the test fixture for PR9020. No real layout done.
    [PRTF02.brd, PRTF02.sch]
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2015-03-05 PR8002 Updates
    Progress on the Etest fixture schematic and layout
    [PR8002.brd, PR8002.sch]
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2015-03-06 PR8002 Updates
    Placed 26 pin header for RPIB+ as well as Andy’s other comments:
    1. Tac1-4 pull up resistors need to go to +3V3 from the RPi, not
    3.0V_DUT.
    2. I think R1, R3 R9 are all way too high value - I would expect 470R -
    1K
    3. I suggest putting a trimmer down across A_OUT/A_IN/GND to facilitate
    the testing of SMT-only boards, that way the operator can pick the
    level that works for the line.
    4. SW_IN/SW_OUT should not go to GPIO, they should simple go to two
    ends of a zero ohm resistor.
    5. The trimmer and the zero ohm resistor used in (3) & (4) would be
    depopulated in testers destined for fully assembled boards.
    6. Add a 4K7 pullup to 3V3 (pin 1) on DEV_PRES
    7. The RPi B+ has a 40 pin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
    [PR8002.brd, PR8002.sch, RPi-template-B+_small.brd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]
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2015-03-08 Updated to PR8002
    ERC fix
    [PR8002.brd, PR8002.sch]
2015-03-08 PR8002
    Comparator GPIO fix.
    [PR8002.brd, PR8002.sch]
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2015-04-17 Pushed to PR8003 Test Fixture
    Updated layout on headers and orientation.
    [PR8004.brd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]
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2016-02-13 Updated Layout
    Reworked amp layout (partially complete)
    [PR9023.brd]
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2016-02-29 first update in a while from my end
    the big change here is the speaker footprint itself. i updated that to
    fit Fun’s redesign. i also made some smallish changes to the board
    perimeter and a few of the things inside it - mostly very small changes.
    [PR9023.brd, PR9023.sch]
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2016-03-14 Updated speaker to reflect mech redesign
    changed screw layout, changed speaker cutout.
    i also played with the outer dimension a bit - it’s significantly
    easier to mess with now. i also made it symmetrical, which looks quite
    a bit better in my opinion.
    [PR9020.brd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]
2016-06-01 Updated Speaker Layout
    Modified Pem Nut layout to fix a short due to interference on the
    bottom side between a plated hole and the battery clip housing.
    [PR9023.brd, PR9023.sch]
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2017-04-12 PR9001
    added pass / fail LEDs
    [PR9001.brd, PR9001.sch]
2017-04-21 removed spaces from end of filenames
    i was having trouble cloning this repo on my windows machine. after
    some research, it looks like windows doesn’t like spaces at the end of
    filenames. we had a bunch of folders with names like “Test_Fixtures “,
    so i just removed the space at the end. i *think* this will fix my
    issue.
    [PR8002.brd, PR8002.sch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]
2017-04-25 PR9001 Programming Fixture
    Updated layout and added an additional mounting hole.
    [PR9001.brd, PR9001.sch]
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2017-06-02 Reverse Mount LED
    added a reverse mount LED to our library and populated the board with
    it.
    https://www.digikey.com/product-detail/en/broadcom-limited/HSMC-C265/516
    -1465-2-ND/637725
    [PR9024.brd, PR9024.sch]
2017-06-22 PR9025
    Jumped to PR9025 for DFM modifications.
    -Removed R20,R6,R2 and directly connected amp !shutdown and FMIC !Reset
    to PB1 (pin6) on the mcu
    -Removed R8, R7, R3
    -Removed R30
    -Removed R5 & R4 and replaced with traces
    -Removed R31 current limiting resistor
    This opens up a lot of space around the FMIC. Once we prove these all
    work I can spend more time cleaning up the traces around the board.
    [PR9025.brd, PR9025.sch]
2017-06-27 PR9025
    Updated DFM rework from Josh
    - removed R4 & R5
    - FM_IC Sen tied high
    Simplified board dimension outline
    [PR9025.brd, PR9025.sch]
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2017-07-14 PR9025_B
    This is a WIP. 9025B will incorporate learnings from Josh’s 9025A
    build, and most significantly update the ISP header to be centered on
    the PCB at 35mm. There’s still routing and error checking to be done.
    [PR9025_B.brd, PR9025_B.sch]
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2017-07-15 PR9025B
    Centered ISP header and finished layout.
    Moved optimized placement for reverse mount LED
    Removed R40 and made a short
    Optimized vias placements
    [PR9025_B.brd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]
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2017-07-23 PR9002 Test Fixture
    Added PR9002 test fixture for use with these probes via the isp header:
    -https://www.harwin.com/products/S19-501/
    -https://www.harwin.com/products/P19-2221/
    [PR9001.brd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]
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2017-10-30 removed degenerate signal N$21
    i reached out to a friend on the Fusion 360/Eagle integration team and he tells me this was causing our issue with opening in Eagle 8. no idea where it came from, but it's a polygon with no actual geometry in it. Seems to open fine now!
    [PR9027.brd]
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2017-12-09 PR9028 Updates
    Updated Speaker PEM Nuts:
    - currently designed with top and bottom smd pads
    - top pad 6.6 mm bottom pad 4.72 mm, drill 4.22 mm
    Updated library:
    - there are now 3 PEM nut ‘devices:’ ANT, SPK, SPK_GROUND to match our
    three different PEM nut uses.
    - there are now 2 PEM nut ‘packages:’ ANT, SPK
    Updated layout:
    - minor changes to some vias
    - updated logo placement and URL
    Exported BOM & Gerbers
    Ran DRC:
    - showing errors for speaker Pem nuts & speaker pc pins. need to
    confirm with WAI about plating *all* pem nut holes.
    [PR9028.brd, PR9028.sch, PR9028_BOM.csv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]
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2017-12-14 taiwan alpha pot, logo, battery images, etc
    this is all just tweaking stuff, but it should be easier to maintain in the future.
    * battery images no longer get clipped by pem nuts
    * TPR logo now includes Georgia font, not Futura
    * URL now fits below logo & type
    * Potentiometer package is rolled back to Taiwan Alpha part
    * LED and FET moved
    [PR9028.brd, PR9028.sch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]
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

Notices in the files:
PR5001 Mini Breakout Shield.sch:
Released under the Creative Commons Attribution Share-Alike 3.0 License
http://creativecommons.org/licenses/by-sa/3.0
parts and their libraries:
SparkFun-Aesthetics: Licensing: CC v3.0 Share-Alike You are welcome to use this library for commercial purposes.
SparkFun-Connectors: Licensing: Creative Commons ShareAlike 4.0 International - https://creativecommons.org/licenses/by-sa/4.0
